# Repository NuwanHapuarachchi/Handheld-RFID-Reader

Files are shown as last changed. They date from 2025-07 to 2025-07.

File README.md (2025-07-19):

# Handheld RFID Reader

This repository contains the complete design files, firmware, software, and documentation for a **Handheld High-Frequency (HF) RFID Reader**. This project was developed as a partial fulfillment of the requirements for the module **EN 2161: Electronic Design Realization** at the Department of Electronic & Telecommunication Engineering, University of Moratuwa.

### 📋 Table of Contents

- [Features](#-features)
- [System Architecture](#️-system-architecture)
- [Hardware Design](#️-hardware-design)
- [Antenna Parameters](#-antenna-parameters)
- [PCB Design](#-pcb-design)
- [Enclosure Design](#-enclosure-design)
- [Software & Firmware](#-software--firmware)
- [Gallery](#-gallery)
- [Installation](#-installation)
- [Usage](#-usage)
- [Project Team](#-project-team)
- [Acknowledgments](#-acknowledgments)

### ✨ Features

- **Ergonomic Design**: A comfortable, gun-shaped enclosure with an ergonomic handle, designed in SolidWorks and 3D printed for industry-level durability
- **HF RFID Capability**: Reads HF (13.56 MHz) RFID tags, supporting the ISO 15693 standard
- **Wireless Connectivity**: Integrated ESP8266 Wi-Fi module for direct communication with a cloud database, offering greater range and flexibility compared to Bluetooth
- **Modular PCB Design**: Three separate 2-layer PCBs for the Antenna, MCU, and Power circuits to ensure signal integrity and simplify debugging
- **Rechargeable Power System**: Powered by two 18650 Li-Ion batteries (total capacity ~3600 mAh), with a dedicated charging cradle and a Battery Management System (BMS) for safety and longevity
- **User Interface**: 
  - LED indicators for power, Wi-Fi status, and read confirmation
  - A comprehensive Web Application (Node.js) for system management, data visualization, and device configuration
  - A cross-platform Mobile Application (Flutter) for on-the-go data access and monitoring
- **Centralized Database**: Utilizes Supabase (PostgreSQL) for robust, scalable, and secure data storage with row-level security policies

### 🛠️ Hardware Design

### Key Components

| Component | Selected Model | Reason for Selection |
|---|---|---|
| **RFID Frontend** | NXP PN5180 | High performance, excellent documentation, and support for ISO 15693 |
| **Microcontroller** | Atmel ATmega32U4 | Native USB support, sufficient I/O, and strong community support |
| **Wi-Fi Module** | Espressif ESP8266 | Direct internet access, high data throughput, and large developer community |
| **Battery** | 2x Li-Ion 18650 (3600 mAh) | High capacity for full-shift operation, good availability, and safety |

### 📡 Antenna Parameters

A custom 2-turn PCB trace antenna was designed for the 13.56 MHz frequency. The design was simulated and optimized for performance.

| Parameter | Value | Unit | Description |
|---|---|---|---|
| **Operating Frequency** | 13.56 | MHz | HF RFID frequency |
| **Target Impedance** | 20 | Ω | Antenna impedance |
| **Antenna Dimensions** | 65 x 65 | mm | Physical size |
| **Number of Turns (N)** | 2 | - | Antenna coil turns |
| **Track Width (w)** | 500 | µm | PCB trace width |
| **Gap between tracks (g)** | 500 | µm | Spacing between traces |
| **Simulated Inductance** | 891 | nH | Calculated inductance |
| **Simulated Capacitance** | 2.3 | pF | Calculated capacitance |
| **Simulated Resistance** | 1.180 | Ω | Calculated resistance |

### 🔧 PCB Design

The system uses a modular approach with three separate 2-layer PCBs: **Antenna**, **MCU**, and **Power**. This separation minimizes interference and simplifies manufacturing.

### PCB Modules

| PCB Module | Function | Features |
|---|---|---|
| **Antenna PCB** | RF signal processing | Custom antenna design, impedance matching |
| **MCU PCB** | Main processing unit | ATmega32U4, PN5180 interface, ESP8266 communication |
| **Power PCB** | Power management | BMS, charging circuit, voltage regulation |

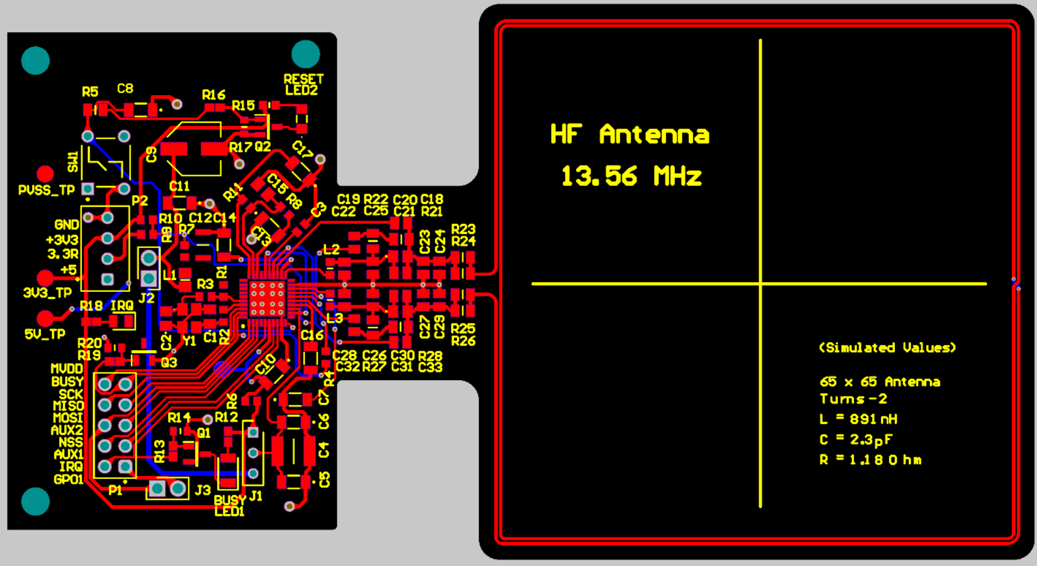
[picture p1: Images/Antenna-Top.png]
Antenna PCB
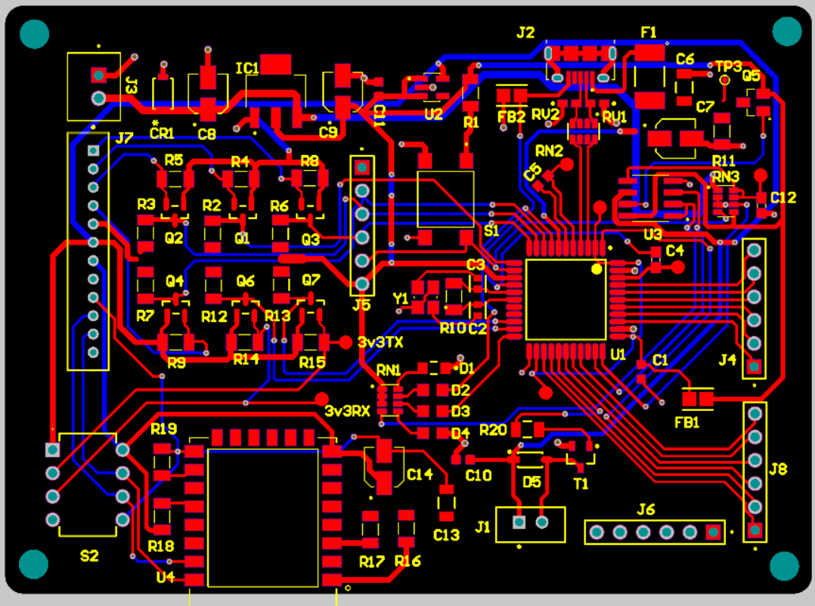
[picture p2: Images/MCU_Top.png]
MCU PCB
 

## 🏠 Enclosure Design

The enclosure and charging cradle were designed in **SolidWorks** for ergonomics, durability, and ease of assembly. The final models were 3D printed using ABS material.

### Design Features
- **Ergonomic gun-shaped design** for comfortable handheld operation
- **Robust ABS construction** for industrial durability
- **Integrated charging cradle** for convenient storage and charging
- **Professional finish** suitable for commercial applications

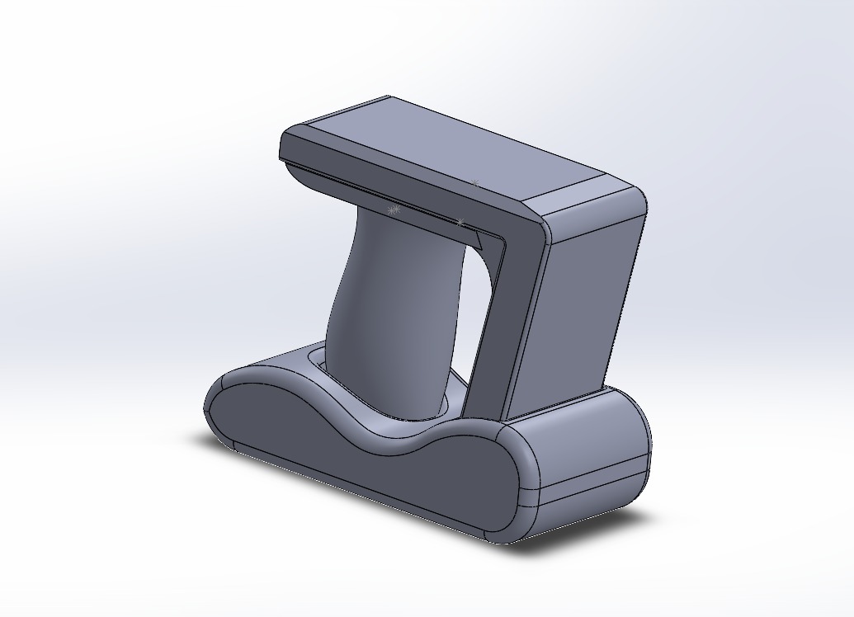
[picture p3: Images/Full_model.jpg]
Model
   

### Database Architecture

The backend uses **Supabase**, which provides a PostgreSQL database, authentication, and real-time APIs. The schema is designed to store information about users, readers, tags, and scan events.

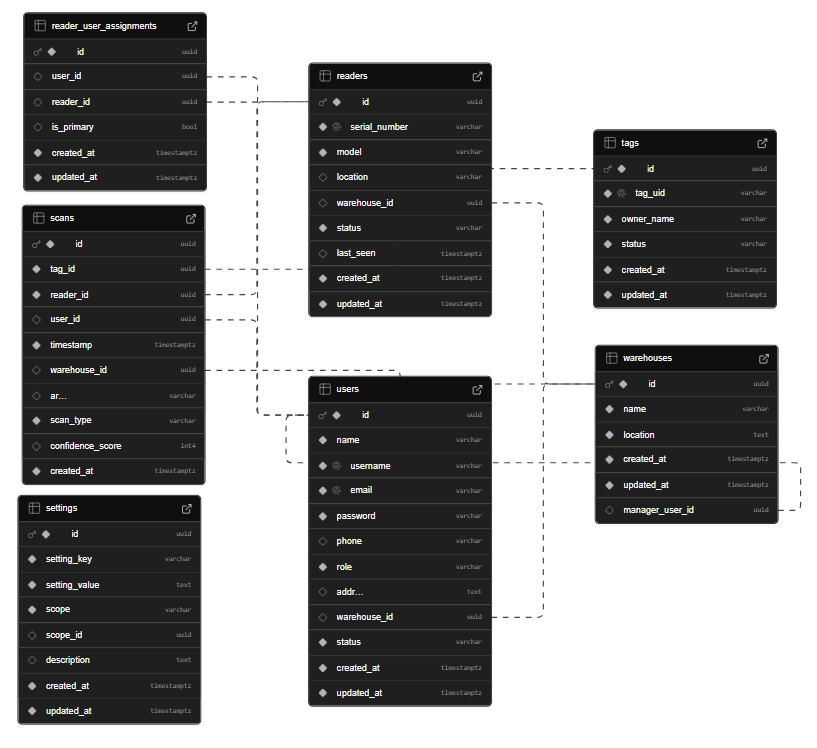
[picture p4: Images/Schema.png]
Database Schema


### Applications

#### Web Application
- **Technology**: Node.js
- **Features**: System management, data visualization, device configuration
- **Interface**: Responsive dashboard for administrators

#### Mobile Application  
- **Technology**: Flutter (Cross-platform)
- **Features**: On-the-go data access, real-time monitoring
- **Platforms**: iOS and Android support

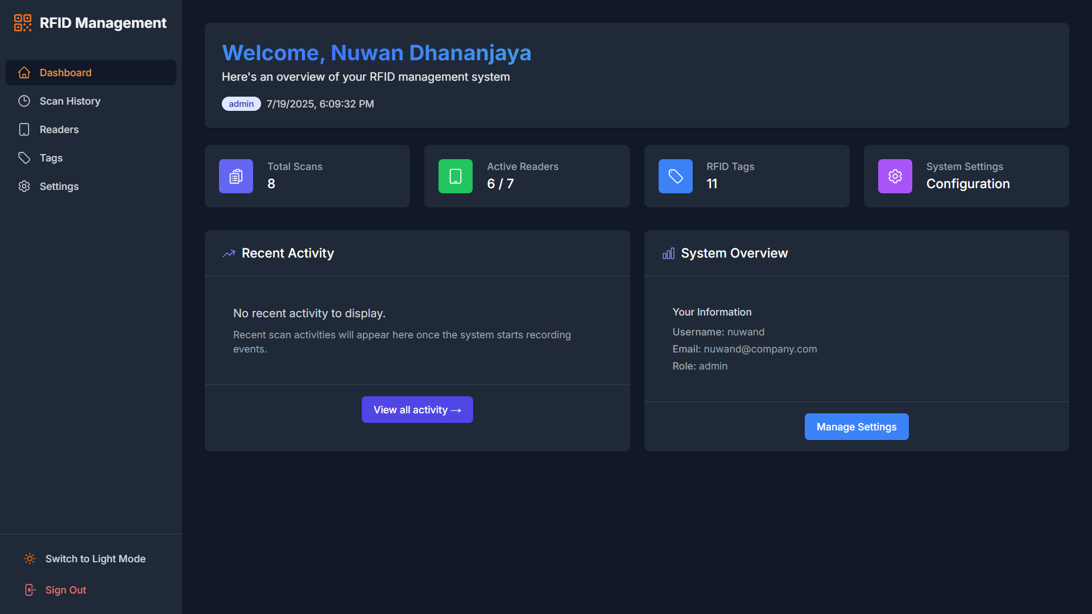
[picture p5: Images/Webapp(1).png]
Web Dashboard
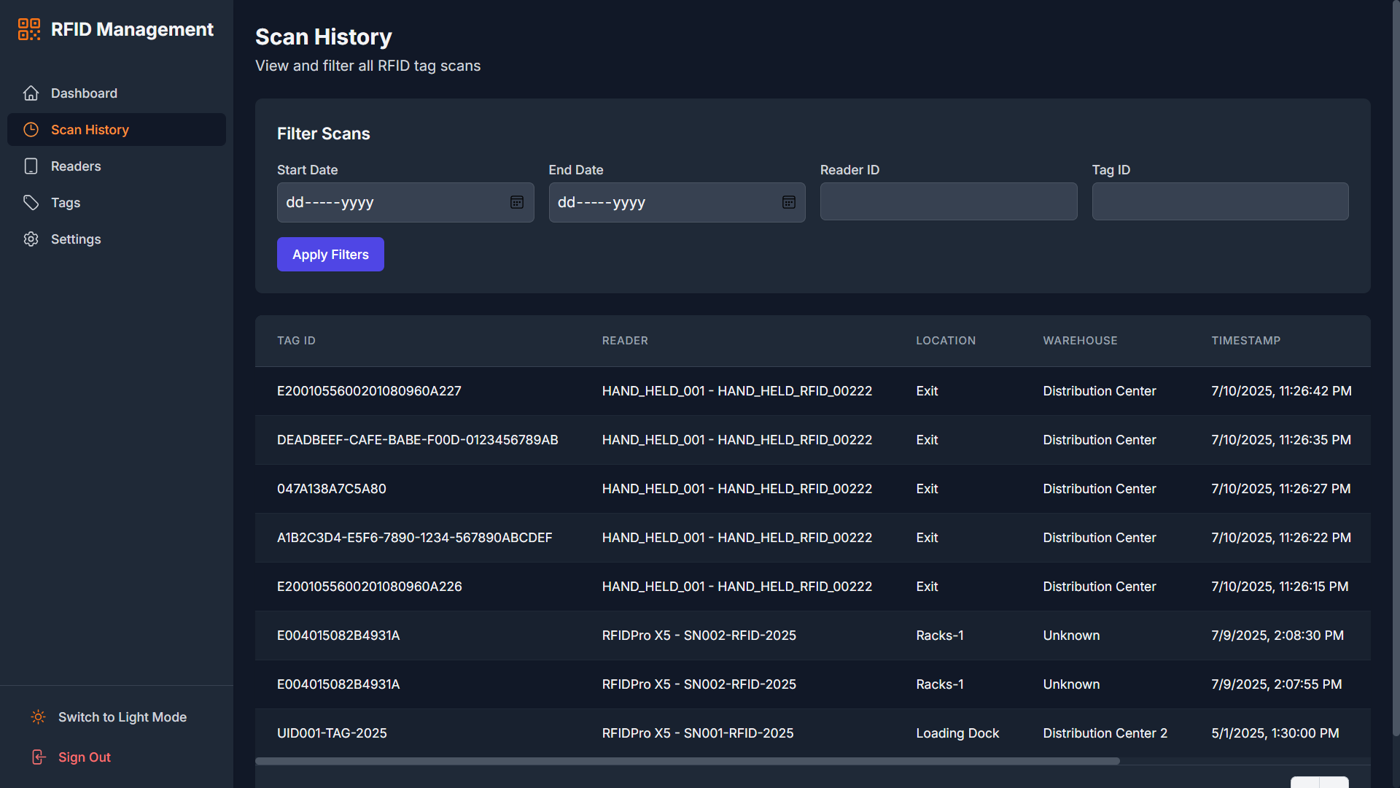
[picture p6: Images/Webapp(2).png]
Mobile Dashboard
 

## 📸 Gallery

### Final Product
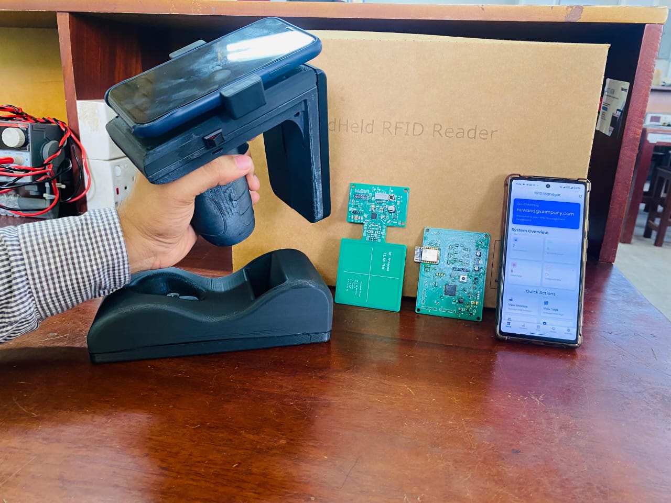
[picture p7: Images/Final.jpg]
3D Printed Final Product


## 🚀 Installation

### Hardware Setup
1. **Assembly**: Follow the assembly guide in `/docs/assembly_guide.pdf`
2. **PCB Installation**: Install the three PCB modules in the enclosure
3. **Battery Installation**: Insert two 18650 Li-Ion batteries
4. **Charging**: Place the device in the charging cradle

### Software Installation
1. **Firmware Upload**: 
   ```bash
   # Upload ATmega32U4 firmware
   avrdude -p atmega32u4 -c avr109 -U flash:w:rfid_reader.hex
   
   # Upload ESP8266 firmware
   esptool.py --port /dev/ttyUSB0 write_flash 0x00000 esp8266_firmware.bin
   ```

2. **Database Setup**:
   - Create a Supabase account
   - Import the database schema from `/database/schema.sql`
   - Configure environment variables

3. **Web Application**:
   ```bash
   cd web-app
   npm install
   npm start
   ```

4. **Mobile Application**:
   ```bash
   cd mobile-app
   flutter pub get
   flutter run
   ```

## 📱 Usage

### Basic Operation
1. **Power On**: Press and hold the power button
2. **Wi-Fi Connection**: Device automatically connects to configured network
3. **Tag Reading**: Point the antenna toward an RFID tag and press the trigger
4. **Data Sync**: Scan data is automatically synchronized to the cloud database
5. **Monitoring**: View real-time data through web or mobile applications

### Configuration
- Access the web dashboard to configure device settings
- Manage user permissions and access levels
- Monitor device status and battery levels
- Export scan data in various formats

## 👥 Project Team

This project was a collaborative effort by the following team members:

| Index No. | Name |
|---|---|
| 220235V | Ilukkumbura I.M.E.I.B. |
| 220212A | Hapuarachchi H.A.D.N.D. |
| 220162T | Fernando C.S.R. |
| 220221B | Hathurusingha H.A.R. |
| 220420J | Nawarathne M.A.A.K. |
| 220700T | Wickramasinghe S.D. |
| 220089B | Cooray M.S.T. |
| 220163X | Fernando D.S. |

## 📄 Documentation

### Available Reports
- **[Design Report](docs/EDR_Design_Report.pdf)**: Complete hardware design documentation
- **[Software Report](docs/Software_Report.pdf)**: Software architecture and implementation details
- **[Assembly Guide](docs/assembly_guide.pdf)**: Step-by-step assembly instructions
- **[User Manual](docs/user_manual.pdf)**: Operating instructions and troubleshooting

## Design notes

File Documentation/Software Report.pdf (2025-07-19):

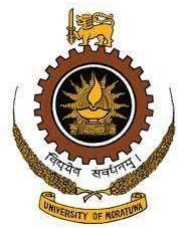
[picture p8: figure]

Department of Electronic & Telecommunication Engineering, University of Moratuwa,
Sri Lanka.

## Software Report Handheld RFID Reader

## Group Members

Index No | Name
220235V | Ilukkumbura I.M.E.I.B.
220212A | Hapuarachchi H.A.D.N.D.
220162T | Fernando C.S.R.
220221B | Hathurusingha HA.R.
220420J | Nawarathne MA.A.K.
220700T | Wickramasinghe S.D.
220089B | Cooray M.S.T.
220163X | Fernando D.S.

## Submitted in partial fulfillment of the requirements for the module EN 2161 Electronic Design Realization

5/22/2025

## Contents

1 PCB Design | 2
2 Enclosure Design | 2
3 Web App Development | 2
4 Database Implementation | 2
5 Schema | 2
6 Firmware Development | 8

1

## 1 PCB Design

## Altium Designer - https://www.altium.com/education/students

## 2 Enclosure Design

## SolidWorks

## 3 Web App Development

The web app was developed using Node.js.

## Link: https://uniofmoramy.sharepoint.com/:f:/g/personal/wickramasinghesd22uomlk/Emx1S− QY ZOlAi52qV PW JZnoBJQriCgSUmRu − N7Q6K0C1tQ?e = sf9qnY

## 4 Database Implementation

The database was implemented using Supabase(PostgreSQL).

## 5 Schema

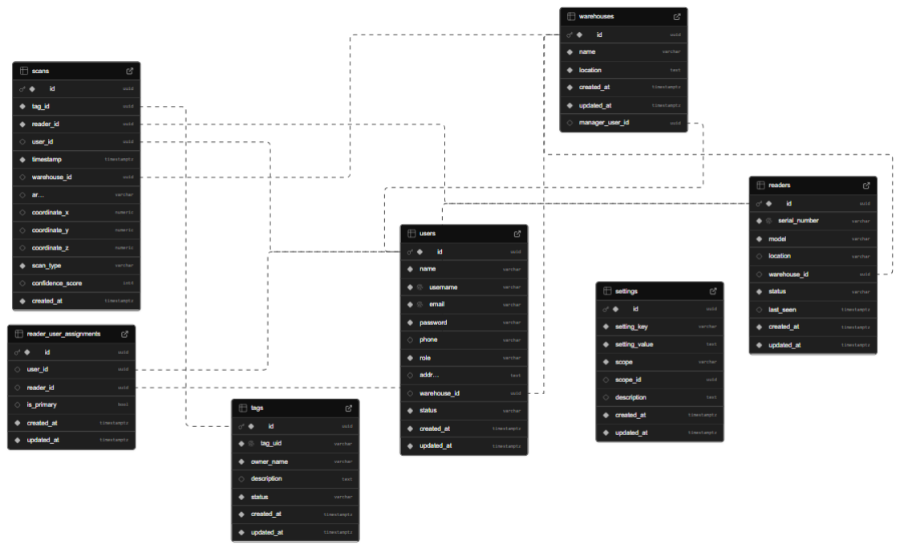
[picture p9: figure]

### Figure 1: Schema

1 | -- Drop tables if they exist for clean migration
2 | DROP TABLE IF EXISTS settings CASCADE ;
3 | DROP TABLE IF EXISTS scans CASCADE ;

2

DROP TABLE IF EXISTS tags CASCADE ;
DROP TABLE IF EXISTS reader_user_assignments CASCADE ; DROP TABLE IF EXISTS readers CASCADE ;
DROP TABLE IF EXISTS users CASCADE ;
DROP TABLE IF EXISTS warehouses CASCADE ;

-- Create warehouses table ( removed the manager_user_id initially to ,→ avoid circular reference )
CREATE TABLE warehouses (
id UUID PRIMARY KEY DEFAULT gen_random_uuid () ,
name VARCHAR (255) NOT NULL ,
location TEXT NOT NULL ,
created_at TIMESTAMPTZ NOT NULL DEFAULT NOW () , updated_at TIMESTAMPTZ NOT NULL DEFAULT NOW ()

) ;

-- Create users table
CREATE TABLE users (
id UUID PRIMARY KEY DEFAULT gen_random_uuid () , name VARCHAR (255) NOT NULL ,
username VARCHAR (100) NOT NULL UNIQUE ,
email VARCHAR (255) NOT NULL UNIQUE ,
password VARCHAR (255) NOT NULL ,
phone VARCHAR (20) ,
role VARCHAR (20) NOT NULL CHECK ( role IN (’admin ’, ’manager ’, ’ ,→ employee ’) ) ,
address TEXT ,
warehouse_id UUID REFERENCES warehouses (id) ON DELETE SET NULL , status VARCHAR (20) NOT NULL DEFAULT ’active ’ CHECK ( status IN (’ ,→ active ’, ’suspended ’, ’inactive ’) ) ,
created_at TIMESTAMPTZ NOT NULL DEFAULT NOW () ,
updated_at TIMESTAMPTZ NOT NULL DEFAULT NOW ()

) ;

-- Now add the manager_user_id to warehouses after users table exists ALTER TABLE warehouses ADD COLUMN manager_user_id UUID ;
ALTER TABLE warehouses ADD CONSTRAINT fk_warehouses_manager
FOREIGN KEY ( manager_user_id ) REFERENCES users (id) ON DELETE SET ,→ NULL ;

-- Create readers table
CREATE TABLE readers (
id UUID PRIMARY KEY DEFAULT gen_random_uuid () , serial_number VARCHAR (100) NOT NULL UNIQUE ,
model VARCHAR (100) NOT NULL ,
location VARCHAR (255) NOT NULL ,
warehouse_id UUID REFERENCES warehouses (id) ON DELETE SET NULL , status VARCHAR (20) NOT NULL DEFAULT ’active ’ CHECK ( status IN (’ ,→ active ’, ’maintenance ’, ’retired ’) ) ,
last_seen TIMESTAMPTZ ,
created_at TIMESTAMPTZ NOT NULL DEFAULT NOW () ,
updated_at TIMESTAMPTZ NOT NULL DEFAULT NOW ()

) ;

-- Create reader_user_assignments table for many - to - many relationship -- This is better than having assigned_user_id in readers table when ,→ multiple users can be assigned
CREATE TABLE reader_user_assignments (
id UUID PRIMARY KEY DEFAULT gen_random_uuid () ,

3

user_id UUID REFERENCES users (id) ON DELETE CASCADE , reader_id UUID REFERENCES readers (id) ON DELETE CASCADE , is_primary BOOLEAN DEFAULT false ,
created_at TIMESTAMPTZ NOT NULL DEFAULT NOW () , updated_at TIMESTAMPTZ NOT NULL DEFAULT NOW () ,
UNIQUE ( reader_id , user_id )

) ;

-- Create tags table
CREATE TABLE tags (
id UUID PRIMARY KEY DEFAULT gen_random_uuid () , tag_uid VARCHAR (100) NOT NULL UNIQUE ,
owner_name VARCHAR (255) NOT NULL ,
description TEXT ,
status VARCHAR (20) NOT NULL DEFAULT ’active ’ CHECK ( status IN (’ ,→ active ’, ’damaged ’, ’retired ’) ) ,
created_at TIMESTAMPTZ NOT NULL DEFAULT NOW () ,
updated_at TIMESTAMPTZ NOT NULL DEFAULT NOW ()

) ;

-- Create scans table
CREATE TABLE scans (
id UUID PRIMARY KEY DEFAULT gen_random_uuid () ,
tag_id UUID NOT NULL REFERENCES tags (id) ON DELETE CASCADE , reader_id UUID NOT NULL REFERENCES readers (id) ON DELETE CASCADE , user_id UUID REFERENCES users (id) ON DELETE SET NULL ,
timestamp TIMESTAMPTZ NOT NULL DEFAULT NOW () ,
warehouse_id UUID REFERENCES warehouses (id) ON DELETE SET NULL , area VARCHAR (255) ,
coordinate_x DECIMAL (10 , 2) ,
coordinate_y DECIMAL (10 , 2) ,
coordinate_z DECIMAL (10 , 2) ,
scan_type VARCHAR (20) NOT NULL CHECK ( scan_type IN (’entry ’, ’exit ’, ,→ ’inventory ’) ) ,
confidence_score INTEGER CHECK ( confidence_score BETWEEN 0 AND 100) , created_at TIMESTAMPTZ NOT NULL DEFAULT NOW ()

) ;

-- Create settings table
CREATE TABLE settings (
id UUID PRIMARY KEY DEFAULT gen_random_uuid () ,
setting_key VARCHAR (100) NOT NULL ,
setting_value TEXT NOT NULL ,
scope VARCHAR (50) NOT NULL DEFAULT ’global ’ CHECK ( scope IN (’global ,→ ’, ’reader ’, ’warehouse ’) ) ,
scope_id UUID , -- This will store reader_id or warehouse_id based on ,→ scope
description TEXT ,
created_at TIMESTAMPTZ NOT NULL DEFAULT NOW () ,
updated_at TIMESTAMPTZ NOT NULL DEFAULT NOW ()

) ;

-- Add a partial unique constraint that treats NULL scope_id as a
,→ specific value
CREATE UNIQUE INDEX idx_settings_unique ON settings ( setting_key , scope , ,→ COALESCE ( scope_id , ’00000000 -0000 -0000 -0000 -000000000000 ’:: UUID ) ) ,→ ;

-- Create functions and triggers for updated_at timestamps

4

109 | CREATE OR REPLACE FUNCTION update_timestamp ()
110 | RETURNS TRIGGER AS $$
111 | BEGIN
112 | NEW . updated_at = NOW () ;
113 | RETURN NEW ;
114 | END ;
115 | $$ language ’plpgsql ’;

116
117 | -- Create triggers for each table
118 | CREATE TRIGGER update_warehouses_timestamp BEFORE UPDATE ON warehouses
119 | FOR EACH ROW EXECUTE PROCEDURE update_timestamp () ;
120 | CREATE TRIGGER update_users_timestamp BEFORE UPDATE ON users
121 | FOR EACH ROW EXECUTE PROCEDURE update_timestamp () ;
122 | CREATE TRIGGER update_readers_timestamp BEFORE UPDATE ON readers
123 | FOR EACH ROW EXECUTE PROCEDURE update_timestamp () ;
124 | CREATE TRIGGER update_tags_timestamp BEFORE UPDATE ON tags
125 | FOR EACH ROW EXECUTE PROCEDURE update_timestamp () ;
126 | CREATE TRIGGER update_settings_timestamp BEFORE UPDATE ON settings
127 | FOR EACH ROW EXECUTE PROCEDURE update_timestamp () ;
128 | CREATE TRIGGER update_reader_user_assignments_timestamp BEFORE UPDATE ON
,→ | reader_user_assignments
129 | FOR EACH ROW EXECUTE PROCEDURE update_timestamp () ;

130
131 | -- Create indexes for performance
132 | CREATE INDEX idx_scans_timestamp ON scans ( timestamp ) ;
133 | CREATE INDEX idx_scans_tag_id ON scans ( tag_id ) ;
134 | CREATE INDEX idx_scans_reader_id ON scans ( reader_id ) ;
135 | CREATE INDEX idx_readers_warehouse ON readers ( warehouse_id ) ;
136 | CREATE INDEX idx_users_warehouse ON users ( warehouse_id ) ;
137 | CREATE INDEX idx_tags_status ON tags ( status ) ;
138 | -- We already have the unique index that acts as our index for these
,→ columns
139 | CREATE INDEX idx_reader_assignments_user ON reader_user_assignments (
,→ user_id ) ;
140 | CREATE INDEX idx_reader_assignments_reader ON reader_user_assignments (
,→ reader_id ) ;

141
142 | -- Create RLS ( Row Level Security ) policies for Supabase
143 | -- Enable RLS on all tables
144 | ALTER TABLE warehouses ENABLE ROW LEVEL SECURITY ;
145 | ALTER TABLE users ENABLE ROW LEVEL SECURITY ;
146 | ALTER TABLE readers ENABLE ROW LEVEL SECURITY ;
147 | ALTER TABLE tags ENABLE ROW LEVEL SECURITY ;
148 | ALTER TABLE scans ENABLE ROW LEVEL SECURITY ;
149 | ALTER TABLE settings ENABLE ROW LEVEL SECURITY ;
150 | ALTER TABLE reader_user_assignments ENABLE ROW LEVEL SECURITY ;

151
152 | -- Comprehensive RLS policies

153
154 | -- Warehouse policies
155 | CREATE POLICY " Admins can do anything with warehouses " ON warehouses
156 | FOR ALL TO authenticated
157 | USING ( auth . uid () IN ( SELECT id FROM users WHERE role = ’admin ’) ) ;

158
159 | CREATE POLICY " Managers can update their warehouses " ON warehouses
160 | FOR UPDATE TO authenticated
161 | USING ( auth . uid () = manager_user_id ) ;

162
163 | CREATE POLICY " All users can view warehouses " ON warehouses

5

164 | FOR SELECT TO authenticated
165 | USING ( true ) ;

166
167 | -- User policies
168 | CREATE POLICY " Admins can do anything with users " ON users
169 | FOR ALL TO authenticated
170 | USING ( auth . uid () IN ( SELECT id FROM users WHERE role = ’admin ’) ) ;

171
172 | CREATE POLICY " Managers can view and update users in their warehouse " ON
,→ | users
173 | FOR SELECT TO authenticated
174 | USING (
175 | ( auth . uid () IN ( SELECT id FROM users WHERE role = ’manager ’) )
176 | AND
177 | ( warehouse_id IN ( SELECT warehouse_id FROM users WHERE id = auth
,→ . uid () )
178 | OR warehouse_id IN ( SELECT id FROM warehouses WHERE
,→ manager_user_id = auth . uid () ) )
179 | ) ;

180
181 | CREATE POLICY " Users can view their own data " ON users
182 | FOR SELECT TO authenticated
183 | USING (id = auth . uid () ) ;

184
185 | -- Reader policies
186 | CREATE POLICY " Admins can do anything with readers " ON readers
187 | FOR ALL TO authenticated
188 | USING ( auth . uid () IN ( SELECT id FROM users WHERE role = ’admin ’) ) ;

189
190 | CREATE POLICY " Managers can manage readers in their warehouse " ON
,→ readers
191 | FOR ALL TO authenticated
192 | USING (
193 | ( auth . uid () IN ( SELECT id FROM users WHERE role = ’manager ’) )
194 | AND
195 | ( warehouse_id IN ( SELECT id FROM warehouses WHERE
,→ manager_user_id = auth . uid () ) )
196 | ) ;

197
198 | CREATE POLICY " Users can view readers they are assigned to" ON readers
199 | FOR SELECT TO authenticated
200 | USING (
201 | id IN (
202 | SELECT reader_id FROM reader_user_assignments
203 | WHERE user_id = auth . uid ()
204 | )
205 | ) ;

206
207 | -- Reader Assignment policies
208 | CREATE POLICY " Admins can do anything with reader assignments " ON
,→ reader_user_assignments
209 | FOR ALL TO authenticated
210 | USING ( auth . uid () IN ( SELECT id FROM users WHERE role = ’admin ’) ) ;

211
212 | CREATE POLICY " Managers can manage reader assignments in their warehouse
,→ " ON reader_user_assignments
213 | FOR ALL TO authenticated
214 | USING (
215 | ( auth . uid () IN ( SELECT id FROM users WHERE role = ’manager ’) )

6

216 | AND
217 | ( reader_id IN (
218 | SELECT id FROM readers
219 | WHERE warehouse_id IN (
220 | SELECT id FROM warehouses
221 | WHERE manager_user_id = auth . uid ()
222 | )
223 | ) )
224 | ) ;

225
226 | CREATE POLICY " Users can view their reader assignments " ON
| ,→ reader_user_assignments
227 | FOR SELECT TO authenticated
228 | USING ( user_id = auth . uid () ) ;

229
230 | -- Tags policies
231 | CREATE POLICY " Admins can do anything with tags " ON tags
232 | FOR ALL TO authenticated
233 | USING ( auth . uid () IN ( SELECT id FROM users WHERE role = ’admin ’) ) ;

234
235 | CREATE POLICY " All authenticated users can view tags " ON tags
236 | FOR SELECT TO authenticated
237 | USING ( true ) ;

238
239 | -- Scans policies
240 | CREATE POLICY " Admins can do anything with scans " ON scans
241 | FOR ALL TO authenticated
242 | USING ( auth . uid () IN ( SELECT id FROM users WHERE role = ’admin ’) ) ;

243
244 | CREATE POLICY " Managers can view scans in their warehouse " ON scans
245 | FOR SELECT TO authenticated
246 | USING (
247 | ( auth . uid () IN ( SELECT id FROM users WHERE role = ’manager ’) )
248 | AND
249 | ( warehouse_id IN ( SELECT id FROM warehouses WHERE
| ,→ manager_user_id = auth . uid () ) )
250 | ) ;

251
252 | CREATE POLICY " Users can view their scans " ON scans
253 | FOR SELECT TO authenticated
254 | USING ( user_id = auth . uid () ) ;

255
256 | -- Settings policies
257 | CREATE POLICY " Admins can do anything with settings " ON settings
258 | FOR ALL TO authenticated
259 | USING ( auth . uid () IN ( SELECT id FROM users WHERE role = ’admin ’) ) ;

260
261 | CREATE POLICY " All authenticated users can view global settings " ON
| ,→ settings
262 | FOR SELECT TO authenticated
263 | USING ( scope = ’global ’) ;

264
265 | CREATE POLICY " Managers can view and edit settings for their warehouse "
| ,→ ON settings
266 | FOR ALL TO authenticated
267 | USING (
268 | ( auth . uid () IN ( SELECT id FROM users WHERE role = ’manager ’) )
269 | AND
270 | (

7

271 | ( scope = ’warehouse ’ AND scope_id IN (
272 | SELECT id FROM warehouses WHERE manager_user_id = auth . ,→ uid ()
273 | ) )
274 | OR
275 | ( scope = ’reader ’ AND scope_id IN (
276 | SELECT id FROM readers
277 | WHERE warehouse_id IN (
278 | SELECT id FROM warehouses WHERE manager_user_id = ,→ auth . uid ()
279 | )
280 | ) )
281 | )
282 | ) ;

## 6 Firmware Development

## 6.1 Atmgea32u4 Programming Code (.cpp)

1 | # include <avr/io.h>
2 | # include <util / delay .h>
3 | # include <stdio .h>
4 | # include <string .h>
5 | # include <stdint .h>
6 | # include " mySPI .h"
7 | # include " PN5180 .h"
8 | # include " myUART .h"

9
10 | // Define F_CPU if not already defined
11 | # ifndef F_CPU
12 | # define F_CPU 16000000 UL
13 | # endif

14
15 | // Buffer size for UID string
16 | # define UID_STRING_SIZE 32

17
18 | // PN5180 instance ( NSS = PD1 / Pin 2 , BUSY = PB6 / Pin 10 , RST = PB4 / Pin 8)
19 | PN5180 pn5180 (/* NSS / 2 , / BUSY / 10 , / RST */ 8) ;

20
21 | // Function prototypes
22 | int handshake ( void ) ;
23 | int connectWiFi ( void ) ;
24 | void uart_transmit ( const char * data ) ; // For debug output
25 | void uart_transmit_num ( int16_t num ) ; | // For number output

26
27 | int main ( void ) {
28 | // Initialize UART ( USART1 )
29 | USART_Init () ;

30
31 | // Initialize SPI
32 | SPI_init () ;
33 | SPI_setConfig () ;

34
35 | // Initialize PN5180
36 | pn5180 . begin () ;

37

8

38 | // Configure Pin 12 ( PD6 ) as input with pull - up , Pin 6 ( PD7 ) as
,→ output
39 | DDRD &= ~(1 << DDD6 ) ; | // PD6 as input ( button )
40 | DDRD |= (1 << DDD7 ) ; | // PD7 as output ( LED )
41 | PORTD |= (1 << PORTD6 ) ; // Enable pull - up on PD6
42 | PORTD &= ~(1 << PORTD7 ) ; // LED off initially

43
44 | // Handshake with ESP
45 | for ( uint8_t retries = 3; retries > 0; retries - -) {
46 | USART_TransmitCommand (" PING ") ;
47 | int response = handshake () ;
48 | if ( response == 3) break ; // OK received
49 | _delay_ms (500) ;
50 | }

51
52 | // Connect to WiFi
53 | int wifiStatus = connectWiFi () ;
54 | char wifiMsg [32];
55 | snprintf ( wifiMsg , sizeof ( wifiMsg ) , " WiFi Status : %d\r\n", wifiStatus
| ,→ ) ;
56 | uart_transmit ( wifiMsg ) ;

57
58 | // Main loop
59 | while (1) {
60 | if (!( PIND & (1 << PIND6 ) ) ) { // Button pressed ( PD6 low )
61 | _delay_ms (50) ; // Debounce
62 | if (!( PIND & (1 << PIND6 ) ) ) { // Confirm button
,→ press
63 | | uint8_t uid [8];
64 | | if ( pn5180 . getInventoryFake ( uid ) ) {
65 | | char uidStr [17];
66 | | for (int i = 7 , j = 0; i >= 0; i - - ,
| | ,→ j += 2) {
67 | | sprintf ( uidStr + j , "%02 X",
| | ,→ uid [ i ]) ;
68 | | }
69 | | char cmd [32];
70 | | snprintf ( cmd , sizeof ( cmd ) , " SEND :UID
| | ,→ :%s", uidStr ) ;
71 | | USART_TransmitCommand ( cmd ) ; // Send
| | ,→ UID to NodeMCU
72 | | int response = USART_ReceiveCommand
| | ,→ () ;
73 | | char responseMsg [16];
74 | | snprintf ( responseMsg , sizeof (
| | ,→ responseMsg ) , " Response : %d\r\
| | ,→ n", response ) ;
75 | | uart_transmit ( responseMsg ) ;
76 | | if ( response == 3) {
77 | | PORTD |= (1 << PORTD7 ) ; //
| | ,→ LED on
78 | | _delay_ms (500) ;
79 | | PORTD &= ~(1 << PORTD7 ) ; //
| | ,→ LED off
80 | | } else if ( response == 2) {
81 | | // Handle ERROR ( add if
| | ,→ needed )
82 | | }
83 | | }

9

while (!( PIND & (1 << PIND6 ) ) ) { _delay_ms (10) ; // Wait for button ,→ release

}

}

}

}

return 0; // Never reached

}

// UART transmit function for strings void uart_transmit ( const char * data ) { while (* data ) {
while (!( UCSR1A & (1 << UDRE1 ) ) ) ; // Wait for empty transmit ,→ buffer
UDR1 = * data ++; // Send character

}

}

// UART transmit function for numbers
void uart_transmit_num ( int16_t num ) {
char buffer [16];
snprintf (buffer , sizeof ( buffer ) , "%d\r\n", num ) ; uart_transmit ( buffer ) ;

}

// Handshake with ESP
int handshake ( void ) {
_delay_ms (500) ;
USART_TransmitCommand (" PING ") ;
uart_transmit (" Waiting for ESP response ...\ r\n") ;

// Wait for response with timeout (~3 seconds )
char response [ MAX_BUFFER_SIZE ] = {0};
for ( uint32_t i = 0; i < 3000000; i ++) { // Approx 3 seconds at 16 ,→ MHz
USART_ReadString ( response , MAX_BUFFER_SIZE , 1000) ; // Short ,→ timeout per read
if ( strlen ( response ) > 0) {
| char debugMsg [128]; snprintf ( debugMsg , sizeof ( debugMsg ) , " Received from ,→ ESP : %s\r\n", response ) ; uart_transmit ( debugMsg ) ; if ( strcmp ( response , "OK") == 0) {

uart_transmit ("ESP communication successful ,→ .\r\n") ;
return 3;
} else {
uart_transmit ("ESP responded incorrectly .\r\ ,→ n") ;
return -1;
| }

}
_delay_us (1) ; // Small delay

}

uart_transmit (" Timeout waiting for ESP .\r\n") ; return -1;

10

136 | }

137
138 | // Connect to WiFi
139 | int connectWiFi ( void ) {
140 | const uint32_t maxTimeout = 30000000; // ~30 seconds at 16 MHz
141 | const uint32_t retryInterval = 12000000; // ~12 seconds per attempt
142 | uint32_t attemptCount = maxTimeout / retryInterval ;

143
144 | for ( uint32_t attempt = 0; attempt < attemptCount ; attempt ++) {
145 | USART_TransmitCommand (" WIFI : CONNECT ") ;
146 | char response [ MAX_BUFFER_SIZE ] = {0};

147
148 | // Wait for response
149 | for ( uint32_t i = 0; i < retryInterval ; i ++) {
150 | USART_ReadString ( response , MAX_BUFFER_SIZE , 1000) ;
,→ // Short timeout
151 | if ( strlen ( response ) > 0) {
152 | if ( strcmp ( response , "OK") == 0) {
153 | return 3;
154 | } else if ( strcmp ( response , " ERROR ")
,→ | == 0) {
155 | break ;
156 | }
157 | }
158 | _delay_us (1) ; // Small delay
159 | }

160

161 | }
162 | return -1;
163 | }

## 6.2 PN5180 Programming Code (.h)

1 | /*
2 | * PN5180 . h
3 | *
4 | * Created : 5/22/2025 1:47:50 PM
5 | * | Author : AGRA
6 | */

7
8 | # ifndef PN5180_H
9 | # define PN5180_H

10
11 | # include " mySPI .h"

12
13 | // PN5180 Commands
14 | # define PN5180_WRITE_REGISTER | (0 x00)
15 | # define PN5180_WRITE_REGISTER_OR_MASK | (0 x01)
16 | # define PN5180_WRITE_REGISTER_AND_MASK | (0 x02)
17 | # define PN5180_READ_REGISTER | (0 x04)
18 | # define PN5180_WRITE_EEPROM | (0 x06)
19 | # define PN5180_READ_EEPROM | (0 x07)
20 | # define PN5180_SEND_DATA | (0 x09)
21 | # define PN5180_READ_DATA | (0 x0A)
22 | # define PN5180_LOAD_RF_CONFIG | (0 x11)
23 | # define PN5180_RF_ON | (0 x16)
24 | # define PN5180_RF_OFF | (0 x17)

11

25 | // 11.9.1 , Table 73 PN5180 Register Address Overview
26 | # define SYSTEM_CONFIG | (0 x00)
27 | # define IRQ_ENABLE | (0 x01)
28 | # define IRQ_STATUS | (0 x02)
29 | # define IRQ_CLEAR | (0 x03)
30 | # define RX_STATUS | (0 x13)
31 | # define TX_WAIT_CONFIG | (0 x17)
32 | # define TX_CONFIG | (0 x18)
33 | // 11.9.1 , Table 76 IRQ_STATUS Register
34 | # define RX_IRQ_STAT | (1 < <0) | // End of RF reception IRQ
35 | # define TX_IRQ_STAT | (1 < <1) | // End of RF transmission
| ,→ IRQ
36 | # define IDLE_IRQ_STAT | (1 < <2) | // Idle IRQ
37 | # define RFOFF_DET_IRQ_STAT | (1 < <6) | // RF Field OFF detection
| ,→ IRQ
38 | # define RFON_DET_IRQ_STAT | (1 < <7) | // RF Field ON detection IRQ
39 | # define TX_RFOFF_IRQ_STAT | (1 < <8) | // RF Field OFF in PCD IRQ
40 | # define TX_RFON_IRQ_STAT | (1 < <9) | // RF Field ON in PCD IRQ
41 | // 11.9.1 Table 92 RX_STATUS Register
42 | # define RX_COLL_POS (1 < <19) // These bits show the bit position of the
,→ first detected collision in a received frame (7 bits )
43 | # define RX_COLLISION_DETECTED (1 < <18) // This flag is set to 1 , when a
| ,→ collision has occurred
44 | // 11.9.1 Table 97 TX_CONFIG Register
45 | # define TX_DATA_ENABLE (1 < <10) // If set to 1 , transmission of data is
,→ enabled otherwise only symbols are transmitted .

46
47 | // The PN5180 receive buffer can hold a max of 508 bytes
48 | // But we only need to transfer 2 bytes + 8 bytes per tag = 10 bytes for
,→ | a single card
49 | # ifndef READ_BUFFER_SIZE
50 | # define READ_BUFFER_SIZE 10
51 | # endif
52 | // Other constants and enums
53 | enum ISO15693ErrorCode {
54 | EC_NO_CARD = -1 ,
55 | ISO15693_EC_OK = 0 ,
56 | ISO15693_EC_NOT_SUPPORTED = 0 x01 ,
57 | ISO15693_EC_NOT_RECOGNIZED = 0 x02 ,
58 | ISO15693_EC_OPTION_NOT_SUPPORTED = 0 x03 ,
59 | ISO15693_EC_UNKNOWN_ERROR = 0 x0F ,
60 | ISO15693_EC_BLOCK_NOT_AVAILABLE = 0 x10 ,
61 | ISO15693_EC_BLOCK_ALREADY_LOCKED = 0 x11 ,
62 | ISO15693_EC_BLOCK_IS_LOCKED = 0 x12 ,
63 | ISO15693_EC_BLOCK_NOT_PROGRAMMED = 0 x13 ,
64 | ISO15693_EC_BLOCK_NOT_LOCKED = 0 x14 ,
65 | ISO15693_EC_CUSTOM_CMD_ERROR = 0 xA0
66 | };

67
68 | class PN5180 {
69 | public :
70 | PN5180 ( uint8_t nssPin , uint8_t busyPin , uint8_t rstPin ) ;
71 | void begin () ;
72 | void hardReset () ;
73 | bool getInventory ( uint8_t * uid ) ;
74 | bool getInventoryFake ( uint8_t * uid ) ;
75 | void loadISO15693config () ;
76 | bool activateRF () ;
77 | bool disableRF () ;

12

78 | bool checkIdle () ;
79 | void clearIRQ () ;
80 | void setIdle () ;
81 | void activateTransceive () ;
82 | void sendInventoryCmd () ;
83 | void sendEndOfFrame () ;
84 | bool readReceptionBuffer ( uint8_t * buffer , int16_t len) ;
85 | uint32_t readRegister ( uint8_t regAddress ) ;
86 | bool sendBytes ( uint8_t * sendBuffer , size_t sendBufferLen ) ;
87 | bool readBytes ( uint8_t * recvBuffer , size_t recvBufferLen ) ;

88
89 | private :
90 | uint8_t _nss , _busy , _rst ;
91 | // SPISettings _spiSettings ;
92 | uint16_t _commandTimeout = 800;
93 | bool waitUntilAvailable () ;
94 | bool waitUntilBusy () ;
95 | void errorHandler ( ISO15693ErrorCode errorCode ) ;

96
97 | uint8_t * buffer = ( uint8_t *) malloc ( READ_BUFFER_SIZE ) ;
98 | };

99
100 | # endif

## 6.3 SPI Programming Code

6.3.1 .h

1 | # ifndef MYUART_H
2 | # define MYUART_H

3
4 | # include <stdint .h>

5
6 | # define RX_BUFFER_SIZE 64
7 | # define MAX_BUFFER_SIZE 100

8
9 | void USART_Init ( void ) ;
10 | void USART_Transmit ( uint8_t data ) ;
11 | uint8_t USART_Receive ( void ) ;
12 | void USART_TxString ( const char * str) ;
13 | void USART_ReadString ( char * buffer , uint8_t maxLen , uint32_t timeout ) ;
14 | int USART_ReceiveCommand ( void ) ;
15 | void USART_TransmitCommand ( const char * cmd ) ;

16
17 | # endif

### 6.3.2 .cpp

1 | /*
2 | * mySPI . cpp
3 | *
4 | * Created : 5/22/2025 1:46:21 PM
5 | * | Author : AGRA
6 | */

7
8 | # include <avr/io.h>

13

9 | # include <util / delay .h>
10 | # include <stdio .h>
11 | # include <stdint .h>
12 | # include " mySPI .h"

13
14 | // Define F_CPU if not already defined
15 | # ifndef F_CPU
16 | # define F_CPU 16000000 UL
17 | # endif

18

19
20 | // Initialize SPI as Master , Mode 0 ( CPOL =0 , CPHA =0) , 125 kHz ( F_CPU
| ,→ /128)
21 | void SPI_init ( void ) {
22 | // Set MOSI ( PB2 ) , SCK ( PB1 ) , and NSS ( PD1 ) as outputs ; MISO ( PB3 )
| ,→ as input
23 | DDRB |= (1 << DDB2 ) | (1 << DDB1 ) ; // MOSI , SCK
24 | DDRD |= (1 << DDD1 ) ; | // NSS
25 | DDRB &= ~(1 << DDB3 ) ; | // MISO as input

26
27 | // Configure SPI : Master , Mode 0 , 125 kHz
28 | SPCR = (1 << SPE ) | (1 << MSTR ) | (1 << SPR1 ) | (1 << SPR0 ) ;
29 | SPSR &= ~(1 << SPI2X ) ;
30 | }

31
32 | // Reapply SPI configuration ( for PN5180 compatibility )
33 | void SPI_setConfig ( void ) {
34 | // Reapply SPI settings : Master , Mode 0 , 125 kHz
35 | SPCR = (1 << SPE ) | (1 << MSTR ) | (1 << SPR1 ) | (1 << SPR0 ) ;
36 | SPSR &= ~(1 << SPI2X ) ;

37

38 | }

39
40 | // Perform bidirectional SPI transfer
41 | void SPI_transfer ( uint8_t * buffer , size_t length ) {
42 | for ( size_t i = 0; i < length ; i ++) {
43 | SPDR = buffer [ i ]; // Write byte to SPDR
44 | while (!( SPSR & (1 << SPIF ) ) ) ; // Wait for transmission complete
45 | buffer [ i ] = SPDR ; // Read received byte
46 | }
47 | }

48
49 | // Disable SPI
50 | void SPI_end ( void ) {
51 | SPCR &= ~(1 << SPE ) ; // Disable SPI
52 | }

53
54 | // Test SPI communication
55 | void SPI_testCommunication ( void ) {
56 | SPI_init () ;

57
58 | uint8_t data = 0 x55 ; // Arbitrary test byte
59 | uint8_t received ;

60
61 | // Pull NSS ( PD1 ) low to start communication
62 | PORTD &= ~(1 << PORTD1 ) ;
63 | _delay_ms (1) ;

64
65 | // Send and receive 1 byte

14

66 | SPDR = data ;
67 | while (!( SPSR & (1 << SPIF ) ) ) ;
68 | received = SPDR ;

69
70 | // Pull NSS high to end communication
71 | PORTD |= (1 << PORTD1 ) ;
72 | }

## 6.4 UART Programming Code

6.4.1 .h

1 | # ifndef MYUART_H
2 | # define MYUART_H

3
4 | # include <stdint .h>

5
6 | # define RX_BUFFER_SIZE 64
7 | # define MAX_BUFFER_SIZE 100

8
9 | void USART_Init ( void ) ;
10 | void USART_Transmit ( uint8_t data ) ;
11 | uint8_t USART_Receive ( void ) ;
12 | void USART_TxString ( const char * str) ;
13 | void USART_ReadString ( char * buffer , uint8_t maxLen , uint32_t timeout ) ;
14 | int USART_ReceiveCommand ( void ) ;
15 | void USART_TransmitCommand ( const char * cmd ) ;

16
17 | # endif

### 6.4.2 .cpp

1 | /*
2 | * myUART . cpp
3 | *
4 | * Created : 5/22/2025 1:44:47 PM
5 | * | Author : AGRA
6 | */

7
8 | # include <avr/io.h>
9 | # include <util / delay .h>
10 | # include <stdio .h>
11 | # include <string .h>
12 | # include <stdint .h>
13 | # include " myUART .h"

14
15 | // Define F_CPU if not already defined
16 | # ifndef F_CPU
17 | # define F_CPU 16000000 UL
18 | # endif

19
20 | // UART buffers
21 | volatile static uint8_t rx_buffer [ RX_BUFFER_SIZE ] = {0};
22 | volatile static uint16_t rx_count = 0;
23 | volatile static uint8_t uart_tx_busy = 1;
24 | static char rxBuffer [ MAX_BUFFER_SIZE ];

15

static uint8_t index = 0;

// UART transmit function ( for debug output , consistent with previous ,→ files )
static void uart_transmit ( const char * data ) {
while (* data ) {
while (!( UCSR1A & (1 << UDRE1 ) ) ) ; // Wait for empty transmit ,→ buffer
UDR1 = * data ++; // Send character

}

}

// Initialize USART1 : 9600 baud , 8 - bit , 1 stop bit , no parity , ,→ asynchronous
void USART_Init ( void ) {
// Set baud rate to 9600 (16 MHz -> UBRR1 = 103)
UBRR1 = 103;

// Enable transmitter and receiver
UCSR1B = (1 << RXEN1 ) | (1 << TXEN1 ) ;

// Set frame format : 8 - bit data , 1 stop bit , no parity , asynchronous
UCSR1C = (1 << UCSZ11 ) | (1 << UCSZ10 ) ;
UCSR1B &= ~(1 << UCSZ12 ) ; // Ensure 8 - bit data
UCSR1C &= ~((1 << UMSEL11 ) | (1 << UMSEL10 ) | (1 << UPM11 ) | (1 <<
,→ UPM10 ) | (1 << USBS1 ) ) ;

// Normal speed ( disable double speed )
UCSR1A &= ~(1 << U2X1 ) ;

// Debug output
char msg [] = " USART1 initialized \r\n"; uart_transmit ( msg ) ;

}

// Transmit one byte
void USART_Transmit ( uint8_t data ) {
while (!( UCSR1A & (1 << UDRE1 ) ) ) ; // Wait for empty transmit buffer UDR1 = data ;

}

// Receive one byte
uint8_t USART_Receive ( void ) {
while (!( UCSR1A & (1 << RXC1 ) ) ) ; // Wait for data return UDR1 ;

}

// Transmit a null - terminated string void USART_TxString ( const char * str) { while (* str) {
USART_Transmit (* str ++) ;

}

}

// Receive a string into buffer ( non - blocking , with timeout )
void USART_ReadString ( char * buffer , uint8_t maxLen , uint32_t timeout ) { uint8_t index = 0;
buffer [0] = ’\0 ’; // Initialize buffer

16

80 | // Timeout loop (~10 ms at 16 MHz , adjusted for cycles )
81 | while ( timeout > 0) {
82 | if ( UCSR1A & (1 << RXC1 ) ) {
83 | char c = USART_Receive () ;
84 | if ( c == ’\n’) {
85 | buffer [ index ] = ’\0 ’; // Null - terminate
86 | return ;
87 | } else if ( index < maxLen - 1) {
88 | buffer [ index ++] = c ;
89 | } else {
90 | buffer [0] = ’\0 ’; // Overflow , return empty
,→ string
91 | return ;
92 | }
93 | }
94 | _delay_us (1) ; // ~1 | s | delay per iteration
95 | timeout - -;
96 | }
97 | buffer [0] = ’\0 ’; // Timeout , return empty string
98 | }

99
100 | // Receive and parse command
101 | int USART_ReceiveCommand ( void ) {
102 | char response [ MAX_BUFFER_SIZE ];
103 | USART_ReadString ( response , MAX_BUFFER_SIZE , 10000) ; // ~10 ms
| ,→ timeout

104
105 | // Debug output
106 | char debugMsg [128];
107 | snprintf ( debugMsg , sizeof ( debugMsg ) , " Received : %s\r\n", response ) ;
108 | uart_transmit ( debugMsg ) ;

109
110 | if ( strlen ( response ) == 0) {
111 | return 0; // No complete message
112 | }

113
114 | // Compare response
115 | if ( strcmp ( response , "OK") == 0) {
116 | return 1; // Success
117 | } else if ( strcmp ( response , " ERROR ") == 0) {
118 | return 2; // Failure
119 | } else if ( strncmp ( response , "DA", 2) == 0) {
120 | return 3; // Data received
121 | } else {
122 | return -1; // Unknown response
123 | }
124 | }

125
126 | // Transmit command with " CMD:" prefix and ’\n’
127 | void USART_TransmitCommand ( const char * cmd ) {
128 | char buffer [ MAX_BUFFER_SIZE ] = {0};
129 | uint8_t len = strlen ( cmd ) ;

130
131 | // Add " CMD:" prefix and ’\n’ if needed
132 | if ( len > 0 && cmd [ len - 1] != ’\n’) {
133 | snprintf (buffer , MAX_BUFFER_SIZE - 1 , "CMD :%s\n", cmd ) ;
134 | } else {
135 | snprintf (buffer , MAX_BUFFER_SIZE - 1 , "CMD :%s", cmd ) ;
136 | }

17

137
138 | // Ensure null - termination
139 | buffer [ MAX_BUFFER_SIZE - 1] = ’\0 ’;

140
141 | // Send via UART
142 | USART_TxString ( buffer ) ;
143 | }

18

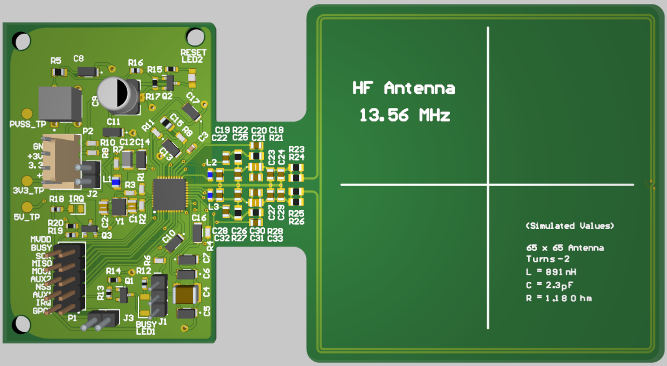
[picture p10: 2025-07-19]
Images/Antenna_3d.png

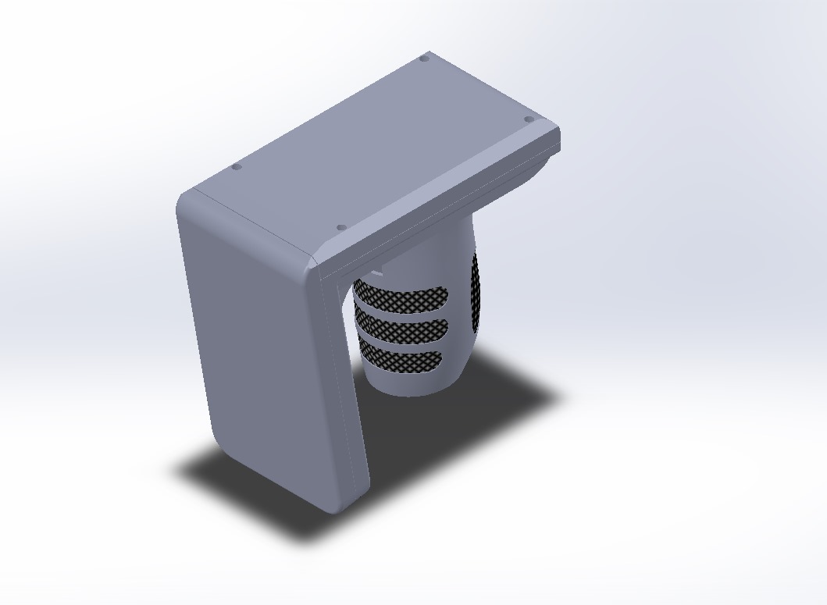
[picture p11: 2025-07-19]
Images/Enclosure.jpg

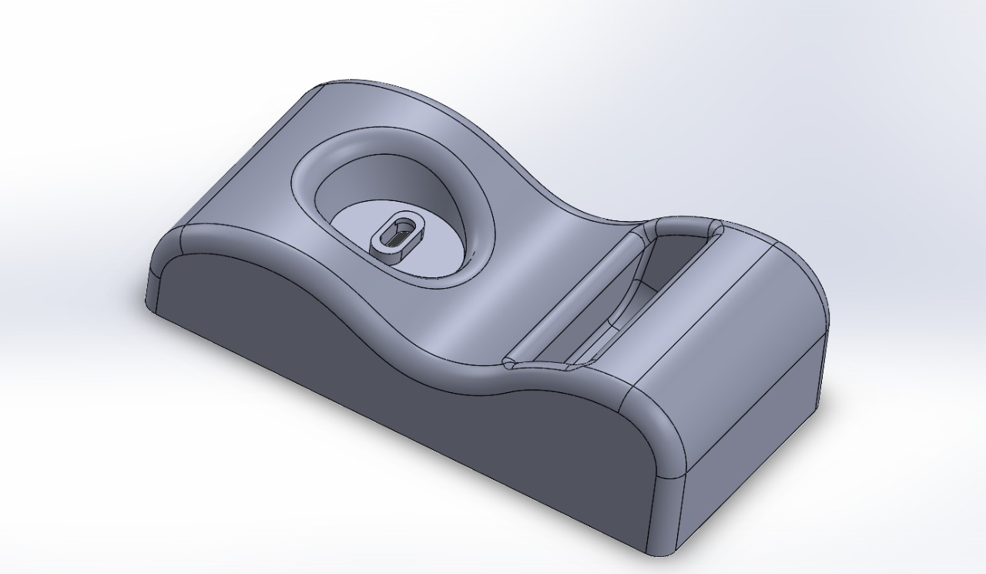
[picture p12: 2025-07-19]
Images/Cradle.jpg

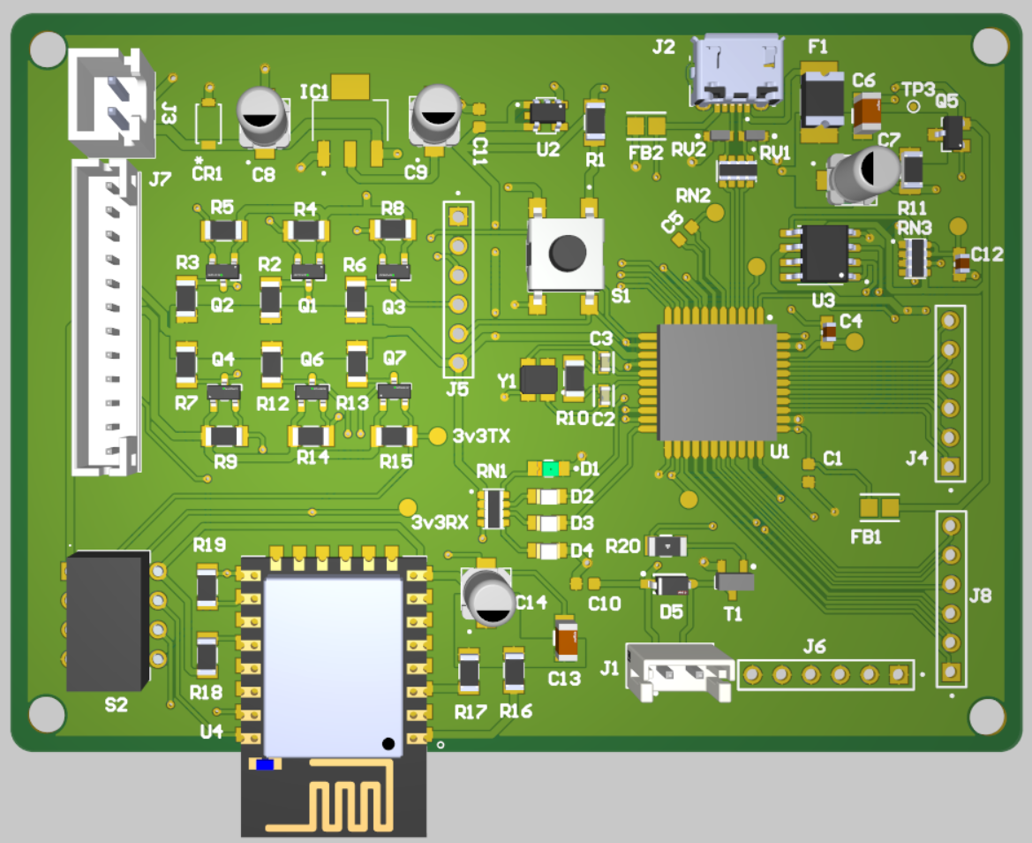
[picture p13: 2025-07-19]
Images/MCU_3d.png

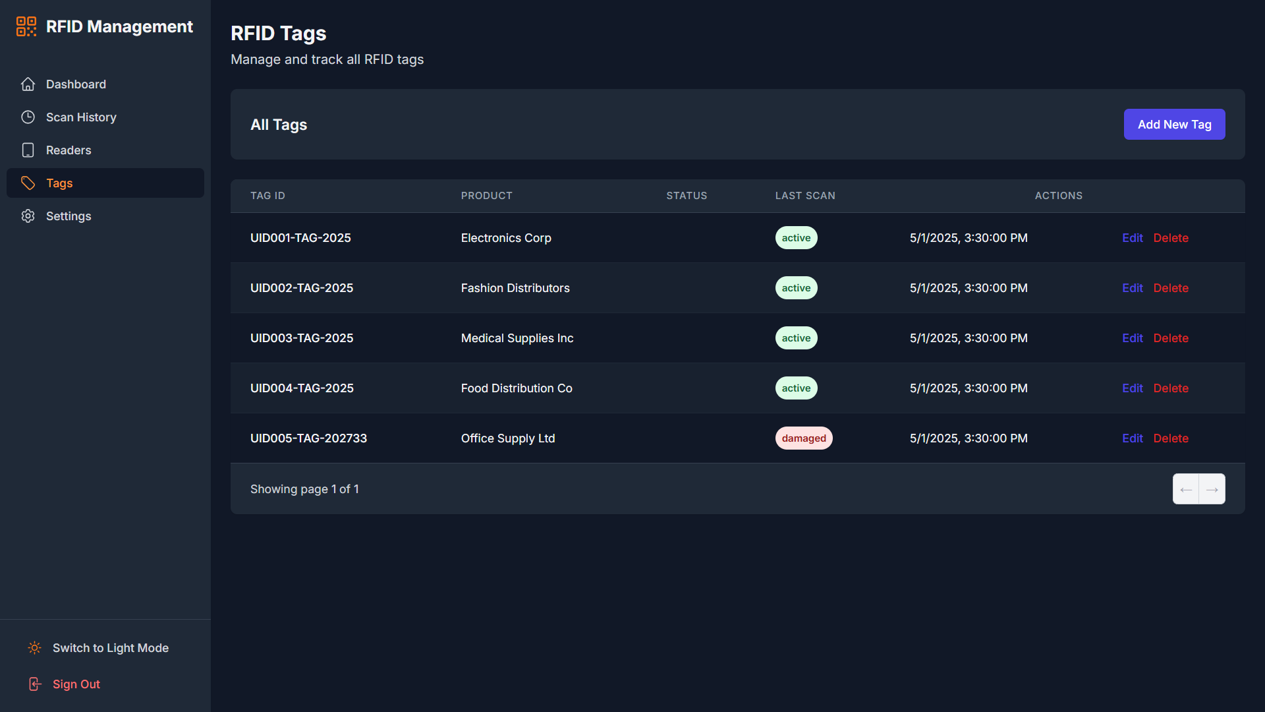
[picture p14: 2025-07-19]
Images/Webapp (4).png

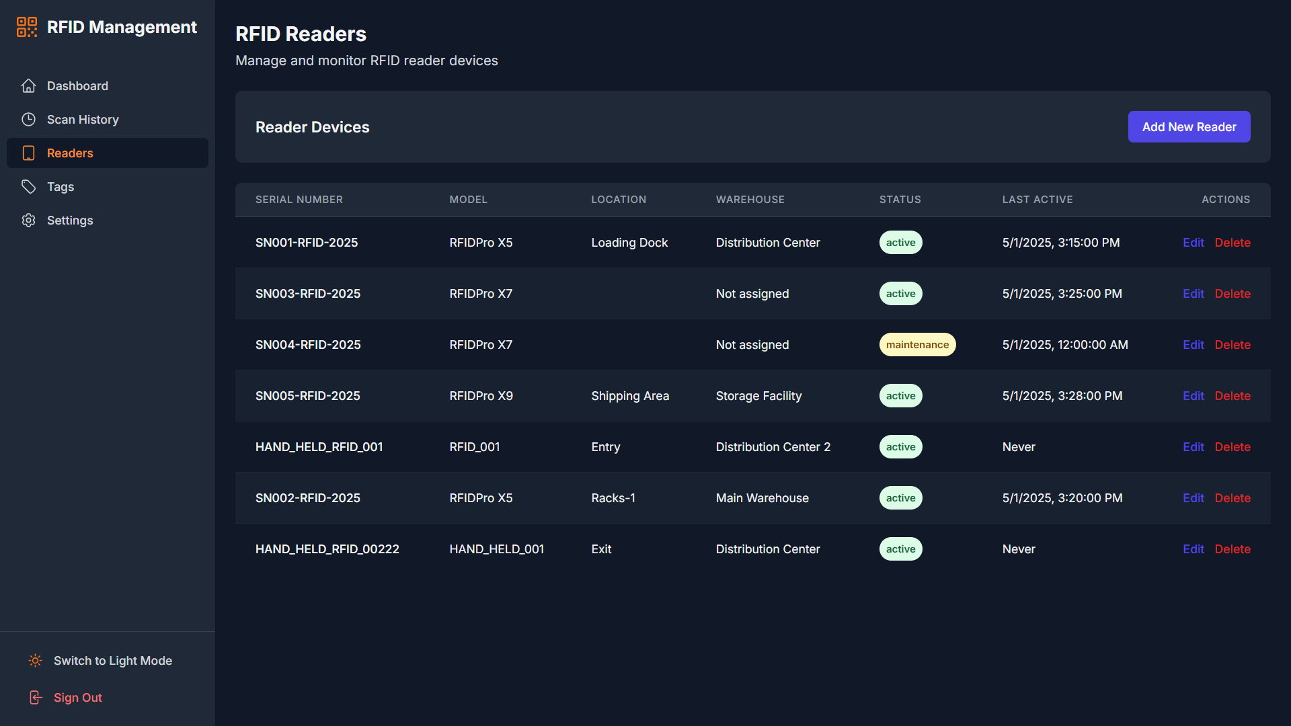
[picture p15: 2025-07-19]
Images/Webapp (3).png

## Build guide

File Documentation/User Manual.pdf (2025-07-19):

# Handheld RFID Reader

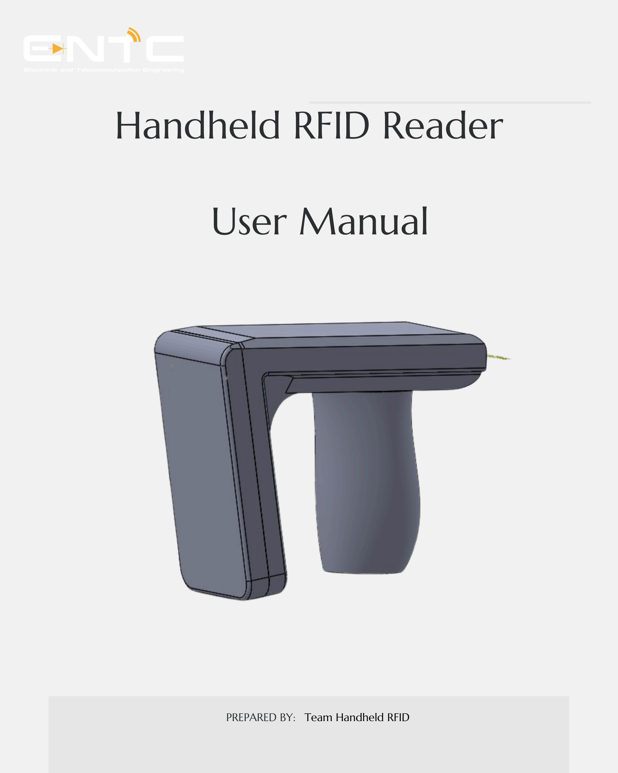
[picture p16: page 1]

# User Manual

PREPARED BY: Team Handheld RFID

# 1.0 IntroductIon

The HF Handheld RFID Reader is a compact, portable device designed for fast and reliable identification and tracking of HF (13.56 MHz) RFID tags. Engineered with ease of use and seamless connectivity in mind, this reader enables users to interact with tagged items through a simple interface while maintaining robust performance across various environments. Whether used for inventory management, access control, healthcare, or retail applications, the HF handheld reader provides a versatile and modern solution for short-range RFID operations. Its ergonomic design, combined with wireless connectivity, makes it ideal for mobile workflows and real-time data collection.

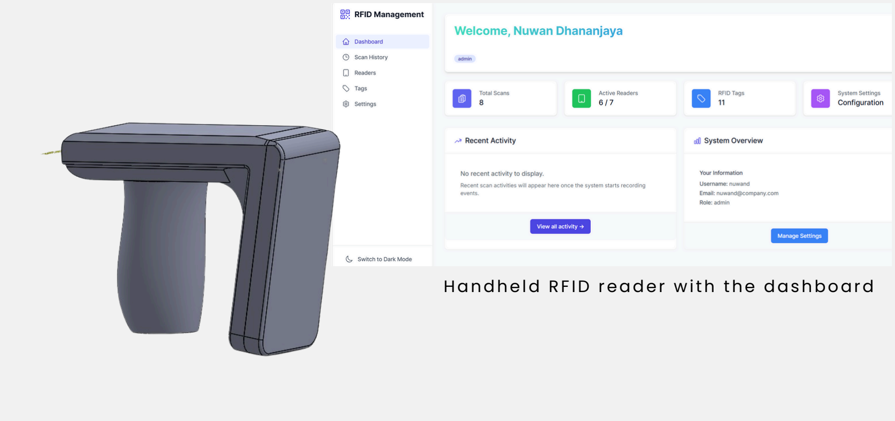
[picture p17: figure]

Handheld RF ID reader with the dashboard

The HF RFID handheld reader can be controlled through a web-based dashboard accessible over Wi-Fi from any device with a modern web browser. Below is an example where it is accessed from a tablet running the Windows operating system:

## RFID.V1 RFID Sled Handheld Reader

Note:
- If you use the web based Dashboard no software installation is required—access the reader entirely through a web interface.
- Ensure the device and the handheld reader are connected to the same Wi-Fi network during setup or operation.
- The dashboard supports all major modern browsers.
Host Platform | Interface Physical Media | Method
Apple iPhone | Web browser (Safari/Chrome) | AppStore App/WebApp
Apple iPad | Web browser (Safari/Chrome) | Appstore App/WebApp
Android Phone | Web browser (Chrome) Wi-Fi | App/WebApp
Windows 10/11 Laptop | Web browser (Edge/Chrome) | Web Dashboard
macOS Laptop/Desktop | Web browser (Safari/Chrome) Wi-Fi | Web Dashboard

## Supported Host Platforms and Connection Types

## 2.1 Product Packaging

1.RFID.V1 : Handheld HF RFID Reader Unit
2.Power Cradle RFID stand
3. Lithium-Ion rechargeable Battery backs,3700Mah (2 pcs)
4. 12V power pack
5.Quick Start Guide (Video Series)
6.User Manual

## 2.2 Key Components

RFID Reader Chip: PN5180
Microcontroller: ATmega32U4
Wi-Fi Module: ESP8266
Power Supply: 2 3.3V Li-Ion rechargeable batteries with a separate charging system cradle. Indicators: LEDs for status and an optional vibration motor for haptic feedback.

# 2.0 Product Specifications

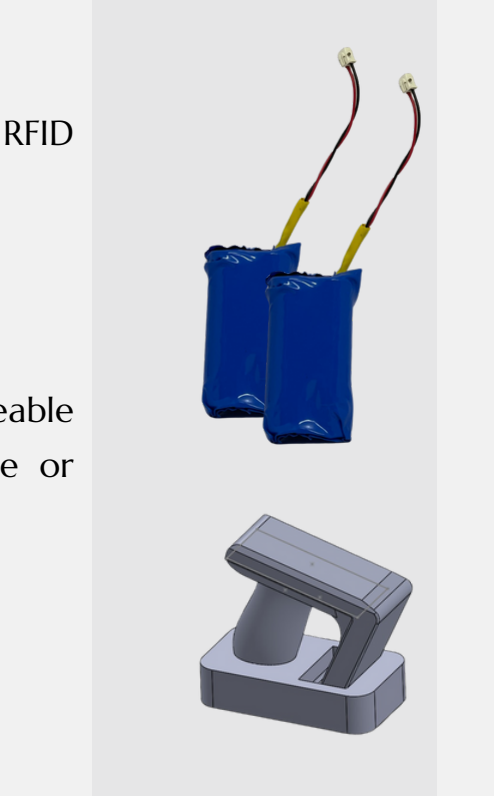
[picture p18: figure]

The following accessories are available for the RFID.V1 Handheld HF RFID Reader

1. RFID.V1 Spare Battery Pack

Each RFID.V1 unit includes two 3700 mAh lithium-ion rechargeable battery packs. Additional batteries are available for extended use or replacement.

2. RFID.V1 Dual Battery Charging Cradle (Power Cradle)

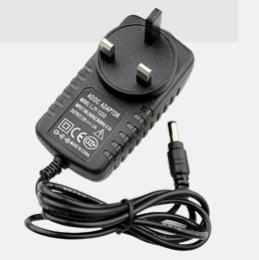
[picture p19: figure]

The Power Cradle serves as both a stand and a dual-slot external battery charger, allowing you to recharge spare battery packs independently of the reader.

3. RFID.V1 12V Power Adapter

A 12V wall adapter compatible with the Power Cradle for efficient charging.

## 3.4 Product Accessories

# 3.0 Getting Started

## 3.1 Introduction

This chapter explains how to set up the device for the first time.

## 3.2 Unpacking

Carefully open the RFID.V1 package and remove all protective plastic coverings. We recommend retaining the original shipping container and internal packaging materials for future storage or transportation.
Verify that the following items are included in the box:

1.RFID.V1 Handheld HF RFID Reader Unit
2.Two (2) Lithium-Ion Rechargeable Battery Packs, 3700 mAh each 3.Power Cradle RFID Stand (Seperate Box)
4.12V Power Pack (for use with the Power Cradle)
5.Quick Start Guide (Video Series Access)
6.User Manual

## 3.3 Features

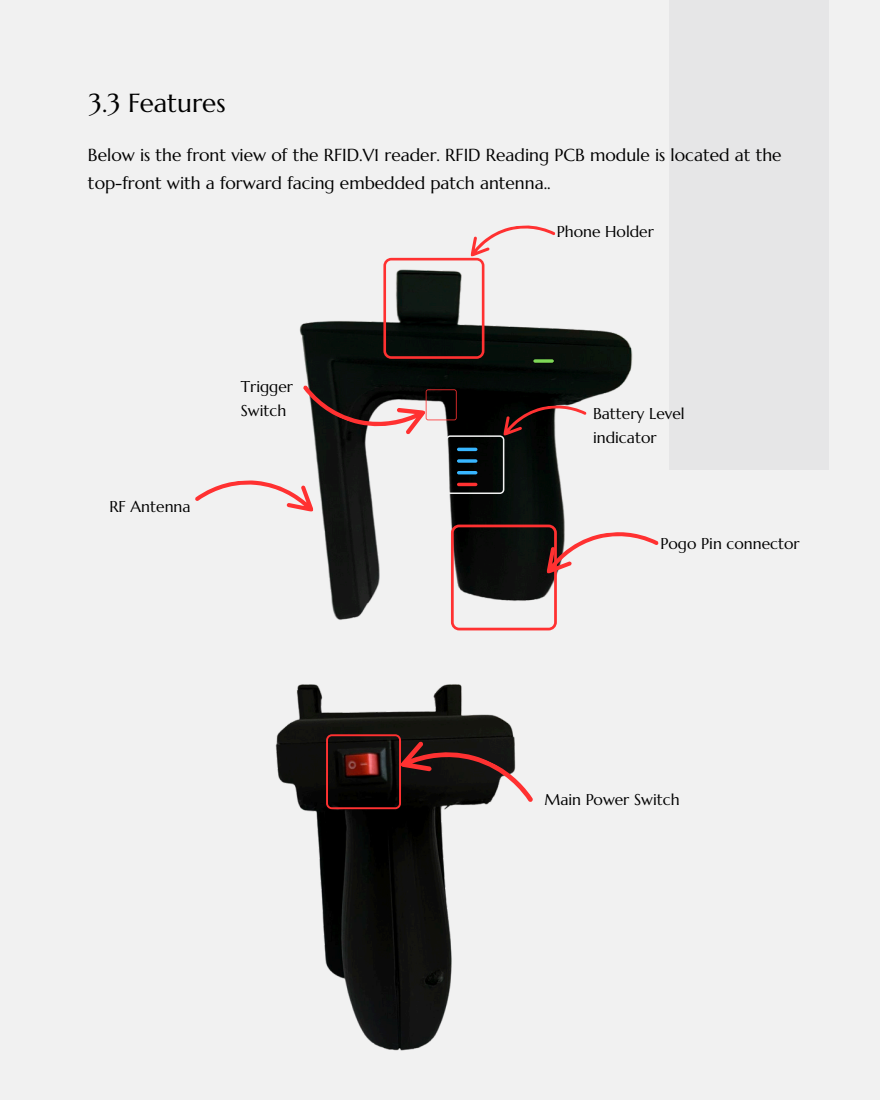
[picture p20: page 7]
Battery Level indicator; Phone Holder; RF Antenna; Trigger Switch

Below is the front view of the RFID.V1 reader. RFID Reading PCB module is located at the
top-front with a forward facing embedded patch antenna..

Pogo Pin connector

Main Power Switch

## 3.4 Powering Up for the first time

## 3.5 Charging the RFID reader

1.Ensure that a fully charged battery is properly inserted into the RFID.V1 unit or that the device is docked in the powered cradle with the 12V adapter connected.
2.Turn on the power switch at the back side of the reader
3. Power LED will turn on to indicate the device is powered. Simultaneously, the red Wi-Fi Setup LED will begin blinking slowly.

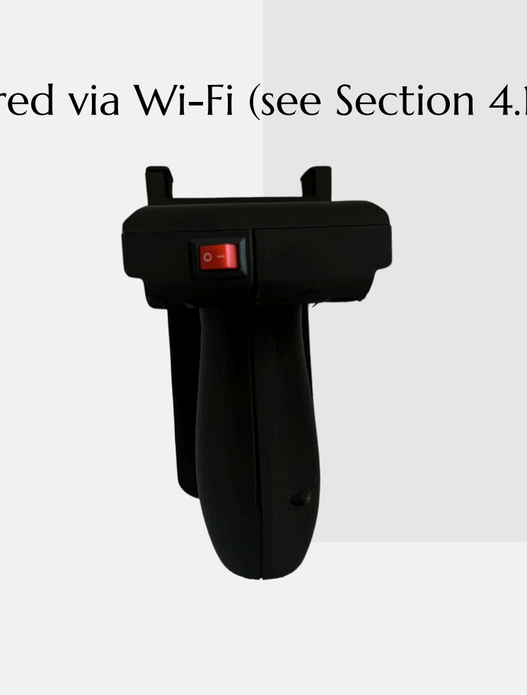
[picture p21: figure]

4.The RFID.V1 is now powered on and ready to be configured via Wi-Fi (see Section 4.1 for connection instructions)

To charge the RFID.V1 handheld reader:

1.Connect the included 12V power adapter to the Power Cradle.
2.Plug the adapter into a standard AC power outlet.
3.Place the RFID.V1 reader securely onto the cradle.
4.Ensure the Battery Charging LED on the side of the reader begins to blink. This indicates that charging is in progress.
5.The current battery level is displayed using a 3-LED battery status array:
- 1 LED = Low charge
- 2 LEDs = Medium charge
- 3 LEDs = Full charge
6. When all three LEDs are lit solid, the battery is fully charged and the Charging LED will turn off or remain solid (depending on device firmware).

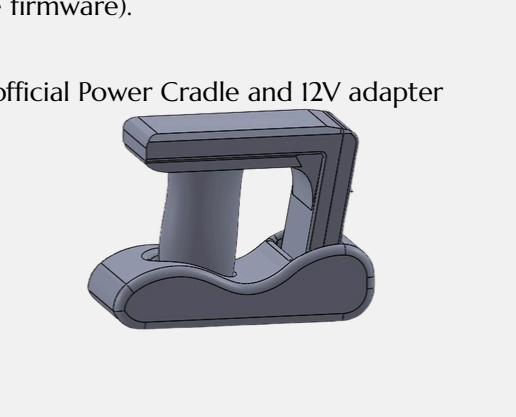
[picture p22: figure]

Note: For optimal battery health, always use the official Power Cradle and 12V adapter supplied with the RFID.V1.

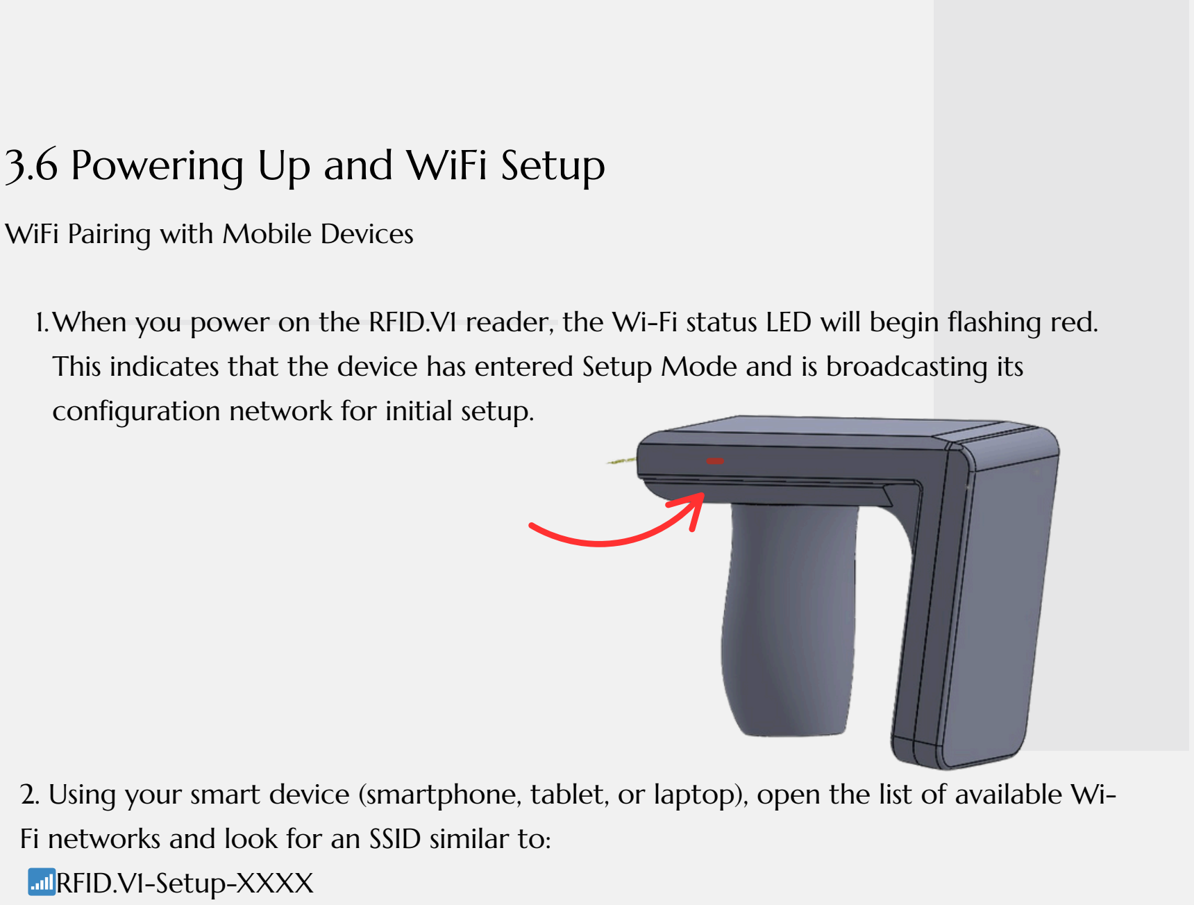
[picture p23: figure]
3.6 Powering Up and WiFi Setup; WiFi Pairing with Mobile Devices; configuration network for initial setup.; 📶RFID.V1-Setup-XXXX

1.When you power on the RFID.V1 reader, the Wi-Fi status LED will begin flashing red. This indicates that the device has entered Setup Mode and is broadcasting its

2. Using your smart device (smartphone, tablet, or laptop), open the list of available Wi-Fi networks and look for an SSID similar to:

(where XXXX is a unique identifier for your device)
3. Connect to the RFID.V1-Setup network.
Password: 1234
4. Once connected, open a web browser on your device and enter the following address into the URL bar:
http://192.168.4.1
5. You will be directed to the RFID.V1 Setup Page. From here, you can:

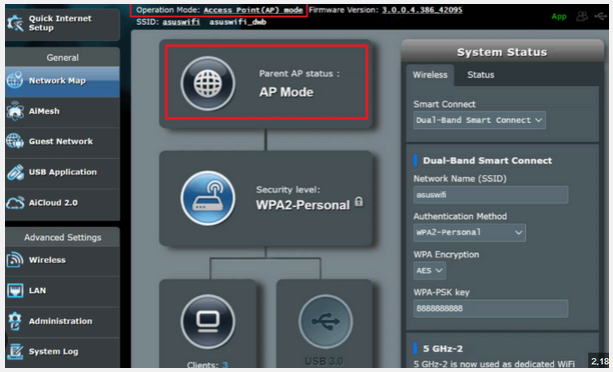
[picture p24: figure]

- View available Wi-Fi networks
- Select your local Wi-Fi network
- Enter your Wi-Fi password
- Save and reboot the device

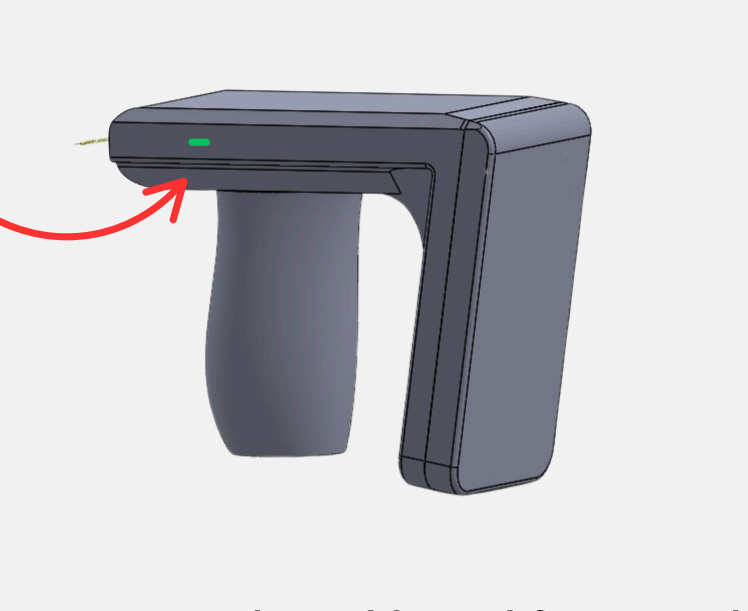
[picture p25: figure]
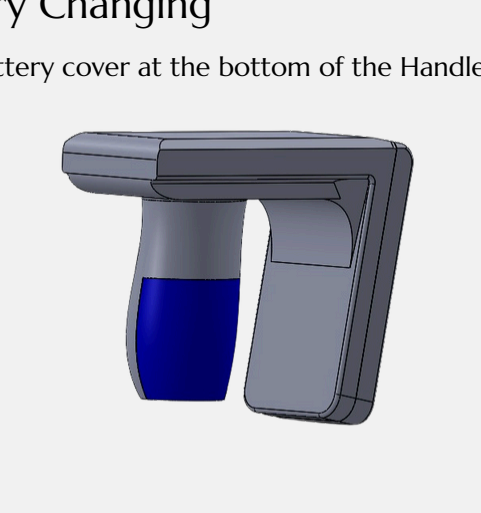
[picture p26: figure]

1. Slide the battery cover at the bottom of the Handle
2. Remove the JST connector of the battery. from the Circuit board
3. Get the Battery Outside and Connect the new battery unit
4. Close the Lid safely
6. After rebooting, the RFID.V1 will automatically connect to the selected Wi-Fi network. The LED will turn solid green to indicate a successful connection.
7. You can now access the RFID.V1 Web Dashboard from any browser on the same network by entering its local IP address (shown during setup or available via the connected router's device list).

## 4.7 Battery Changing

## 3.9 Web App

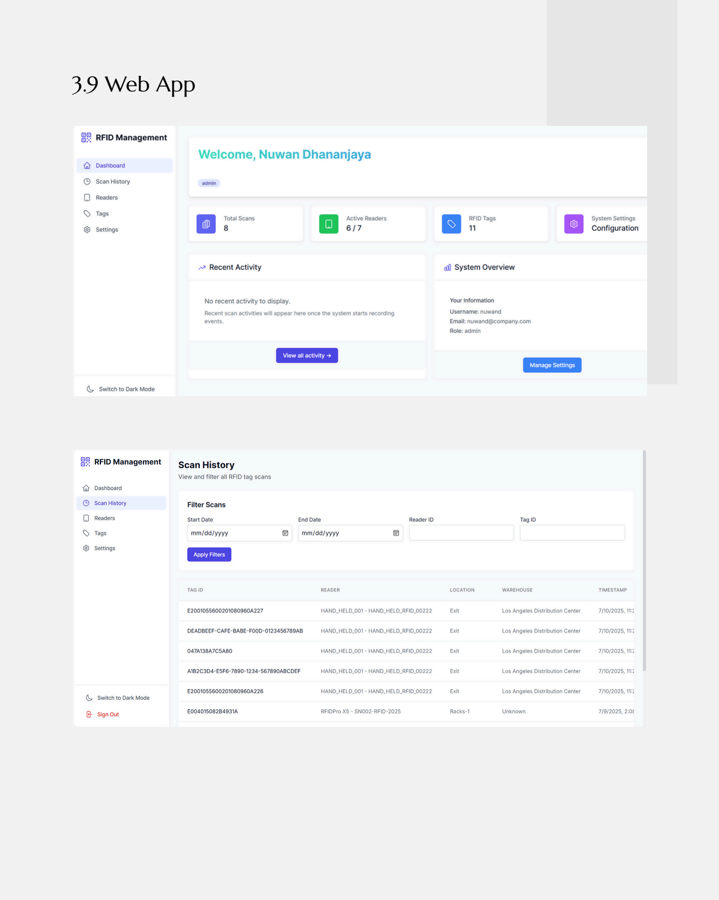
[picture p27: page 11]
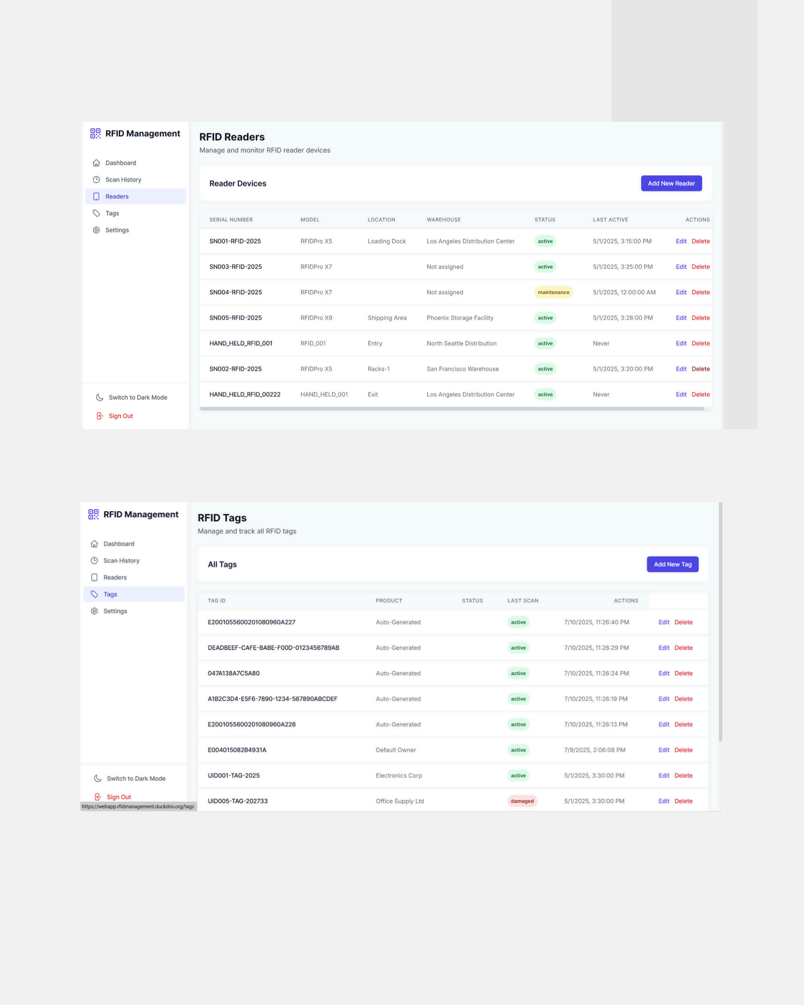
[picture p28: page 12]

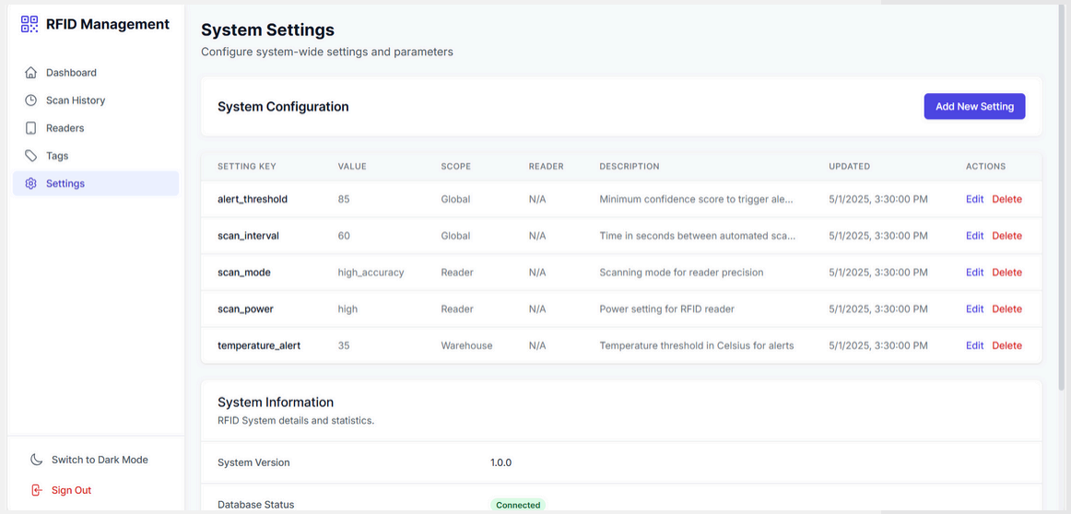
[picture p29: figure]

## 3.10 Mobile Application

Step 1 : After installing the app, open the RFID Manager app and log in with your credentials to view the dashboard

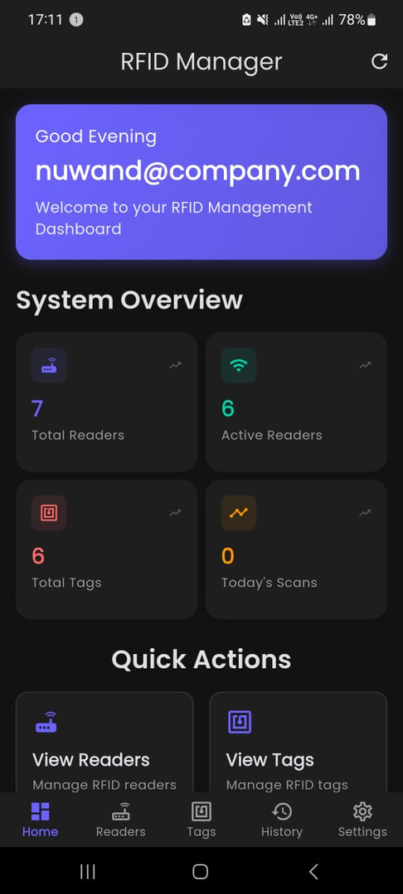
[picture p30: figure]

Step 2 : Tap the "Settings" icon to access your profile and adjust app settings

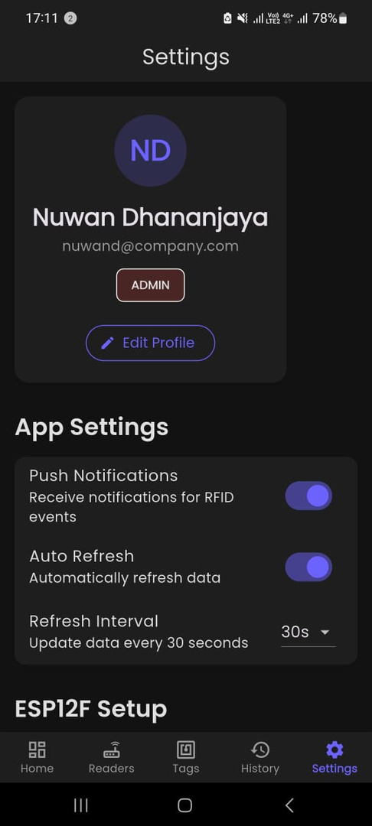
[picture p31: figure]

Step 3 : In the "ESP12F Setup" section, tap "Configure ESP12F WiFi" and select "Open web portal at 192.168.4.1" to set up the WiFi connection.

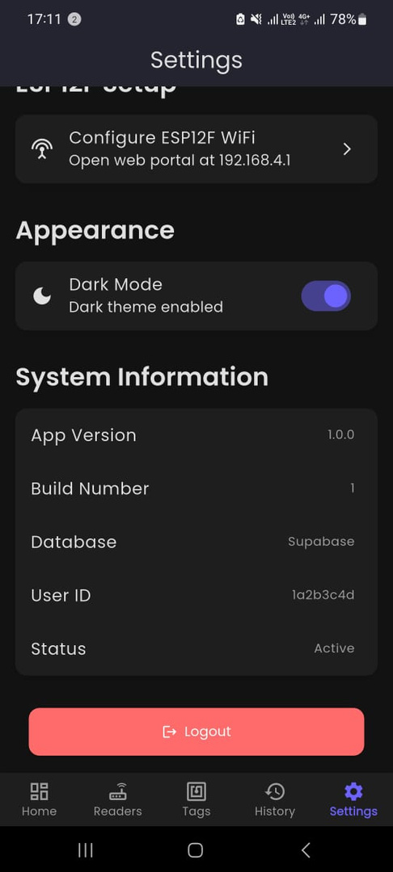
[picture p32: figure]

Step 4 : Afrer cilcking the scan button the user will be able to scan tags

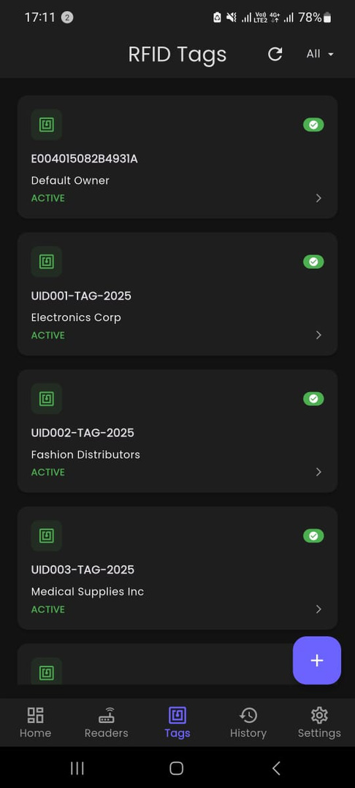
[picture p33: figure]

Step 5 : Tap History to review recent scans

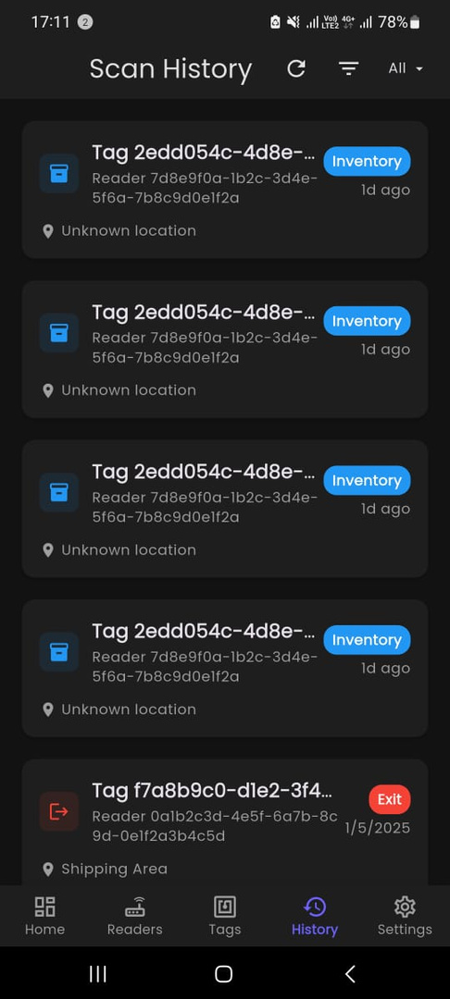
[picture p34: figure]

Step 6 : User will get a notification saying the scannig was done successfully.

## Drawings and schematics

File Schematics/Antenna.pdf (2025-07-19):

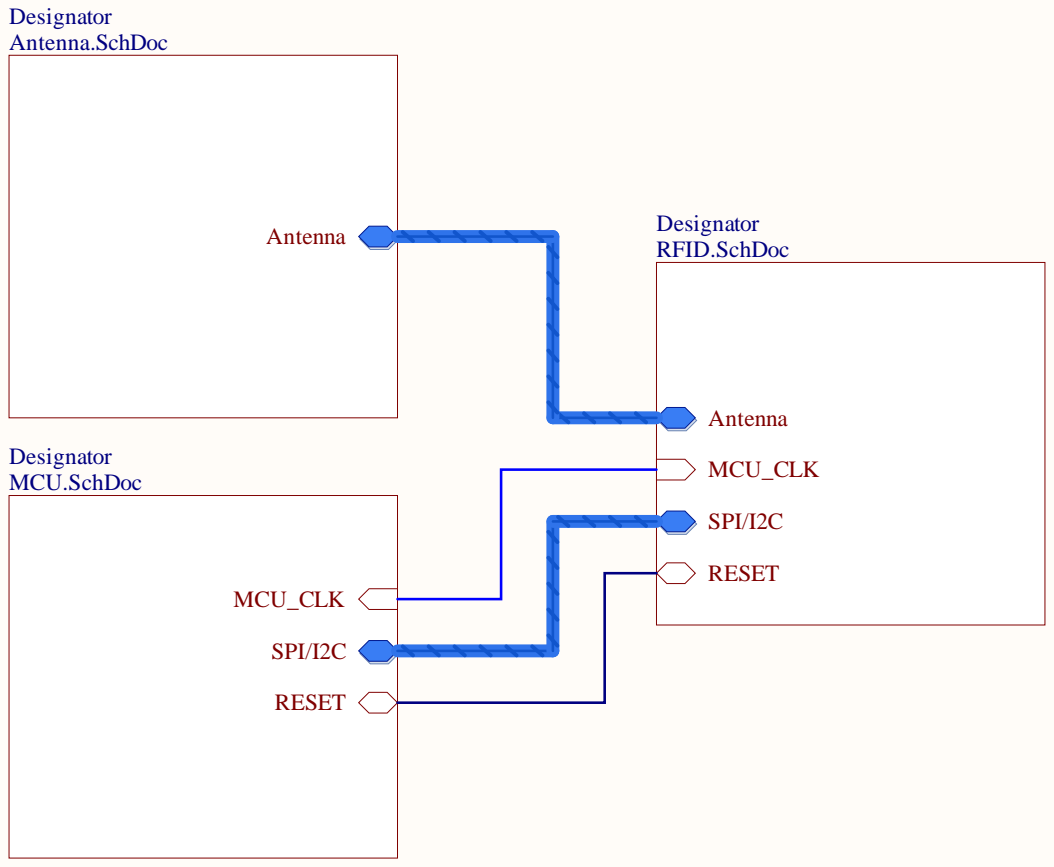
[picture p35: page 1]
Date:; Sheet of; File:; Overview.SchDoc; Drawn By:; HAPUARACHCHI HADND

Title
HandHeld RFID Reader- Antenna

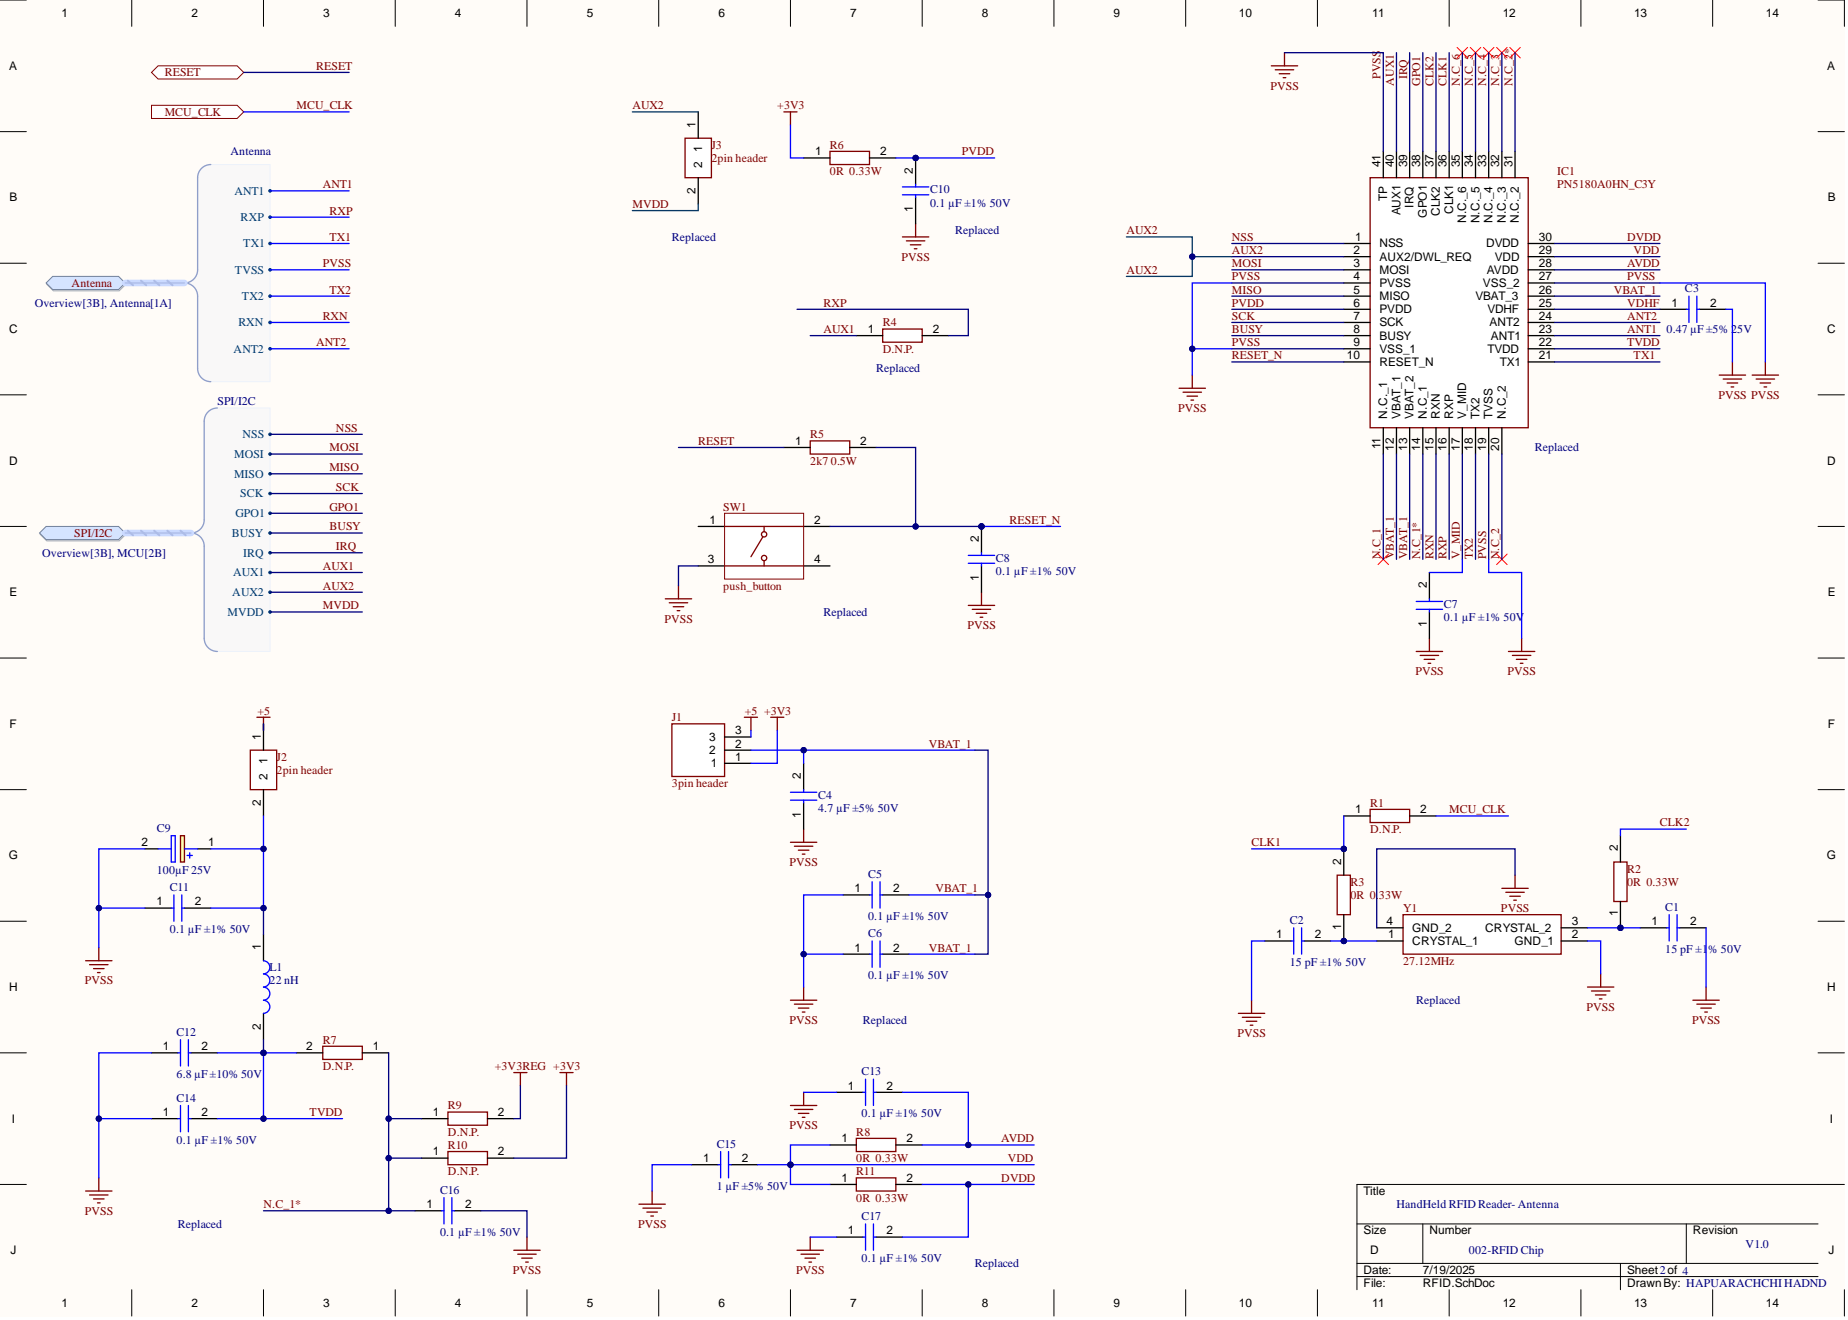
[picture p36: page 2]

Title
HandHeld RFID Reader- Antenna

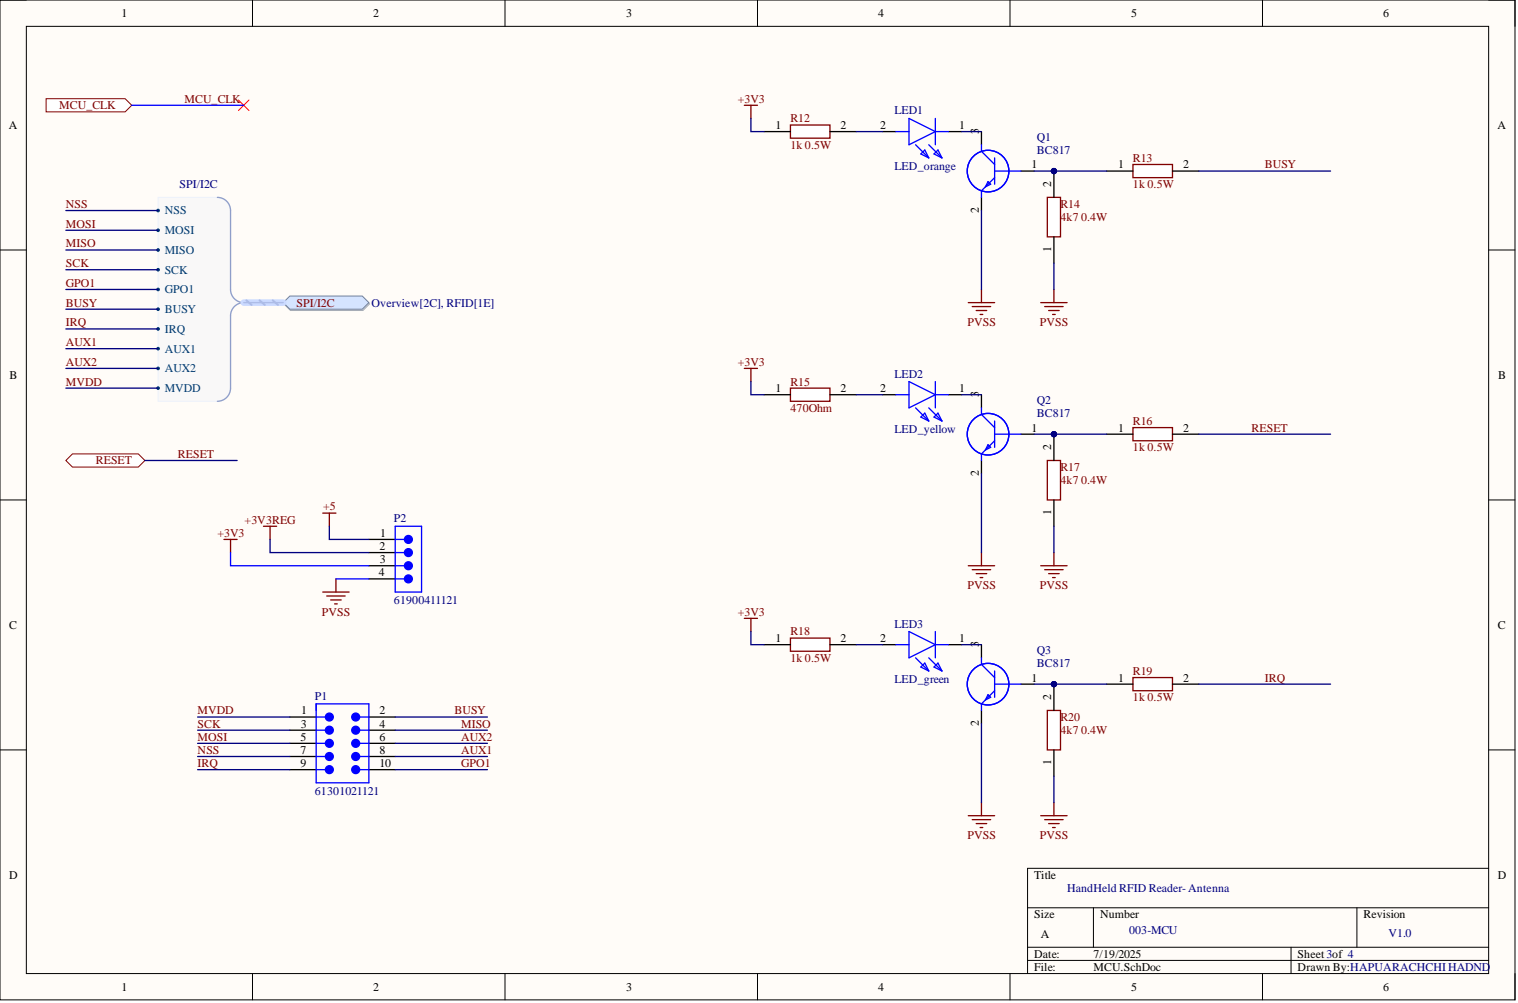
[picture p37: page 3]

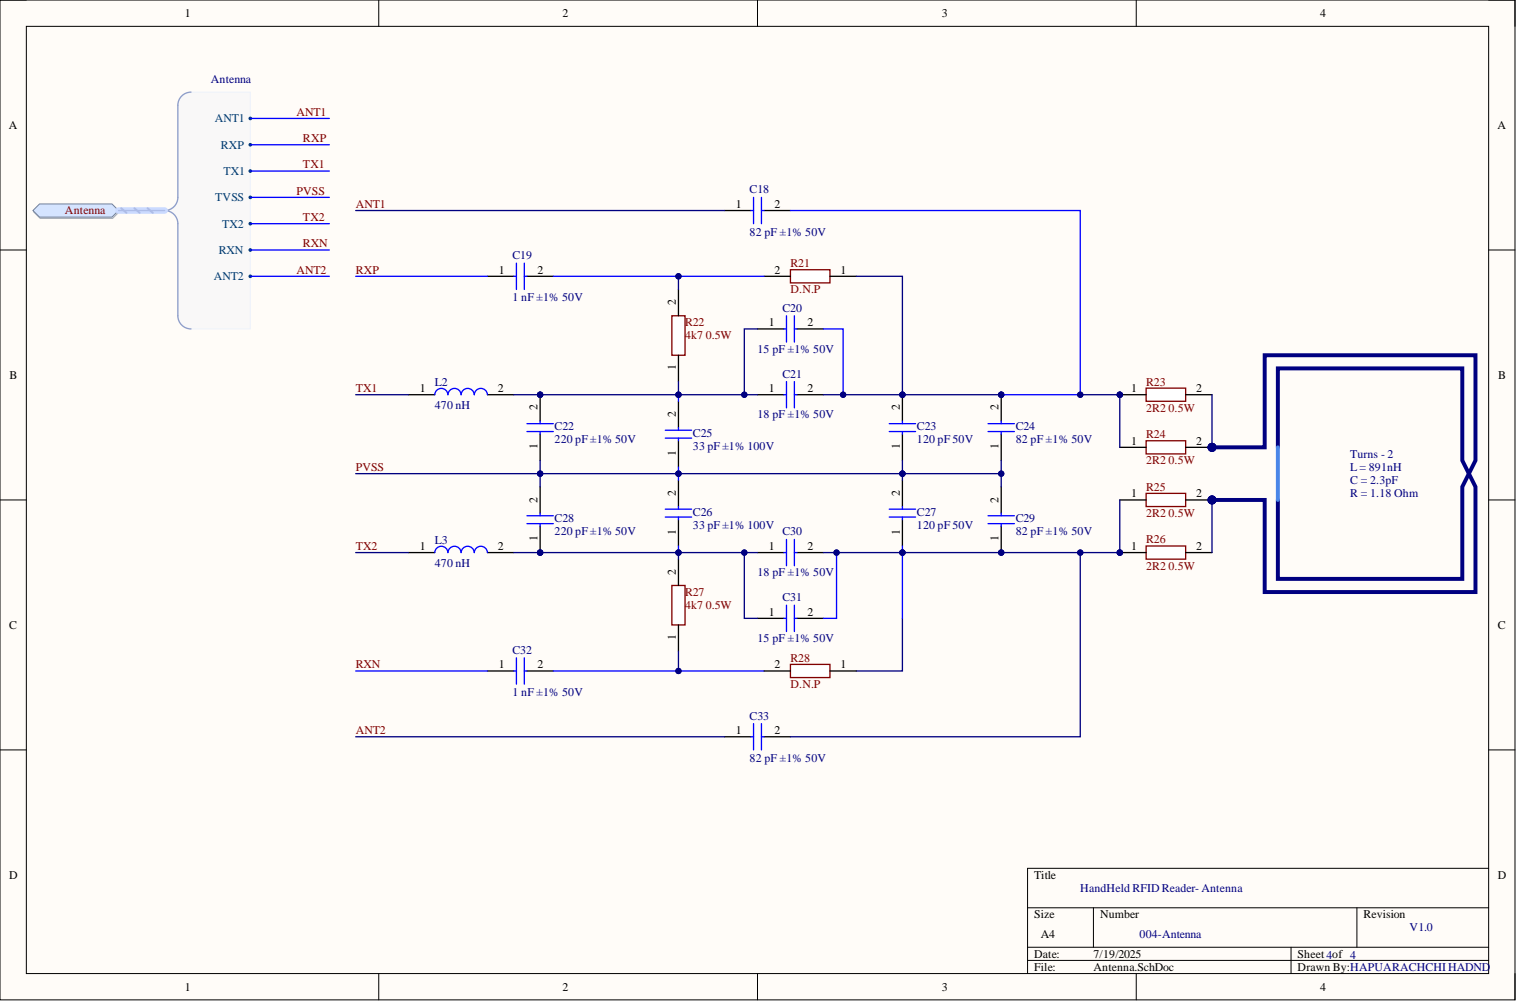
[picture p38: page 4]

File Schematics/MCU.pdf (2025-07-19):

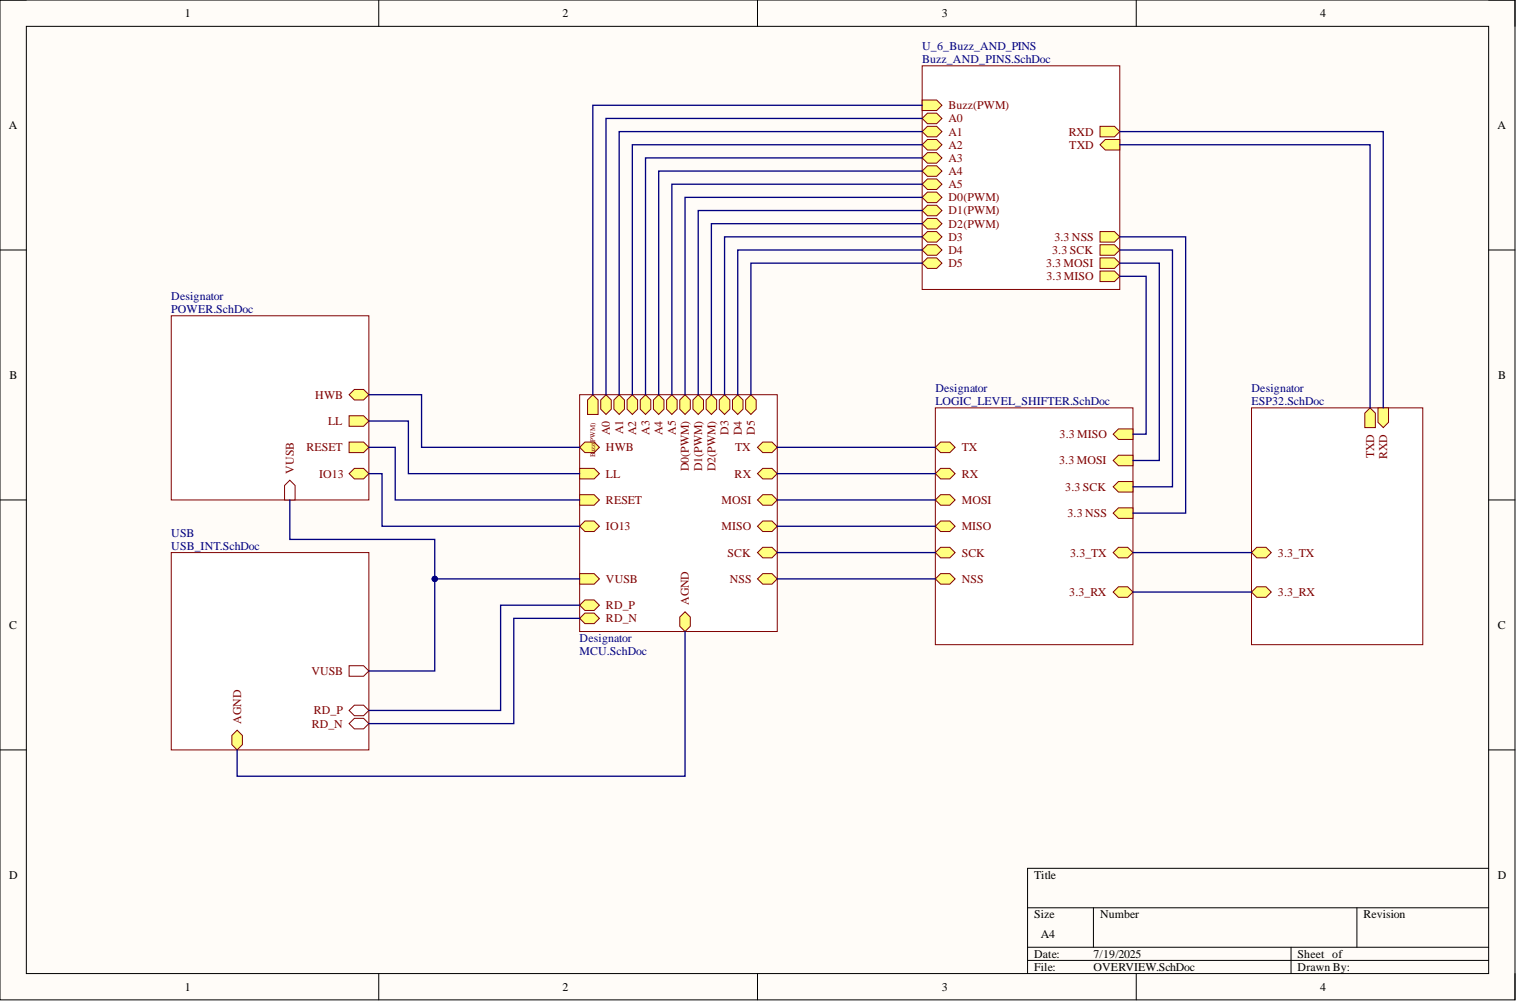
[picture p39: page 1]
Date:; Sheet of; File:; OVERVIEW.SchDoc; Drawn By:; 3.3 MISO; 3.3 MOSI; 3.3 SCK; 3.3 NSS; 3.3 NSS 3.3 SCK 3.3 MOSI 3.3 MISO

HWB TX LL RX RESET MOSI IO13 MISO SCK VUSB NSS RD_P RD_N

VUSB RD_P A RD_N

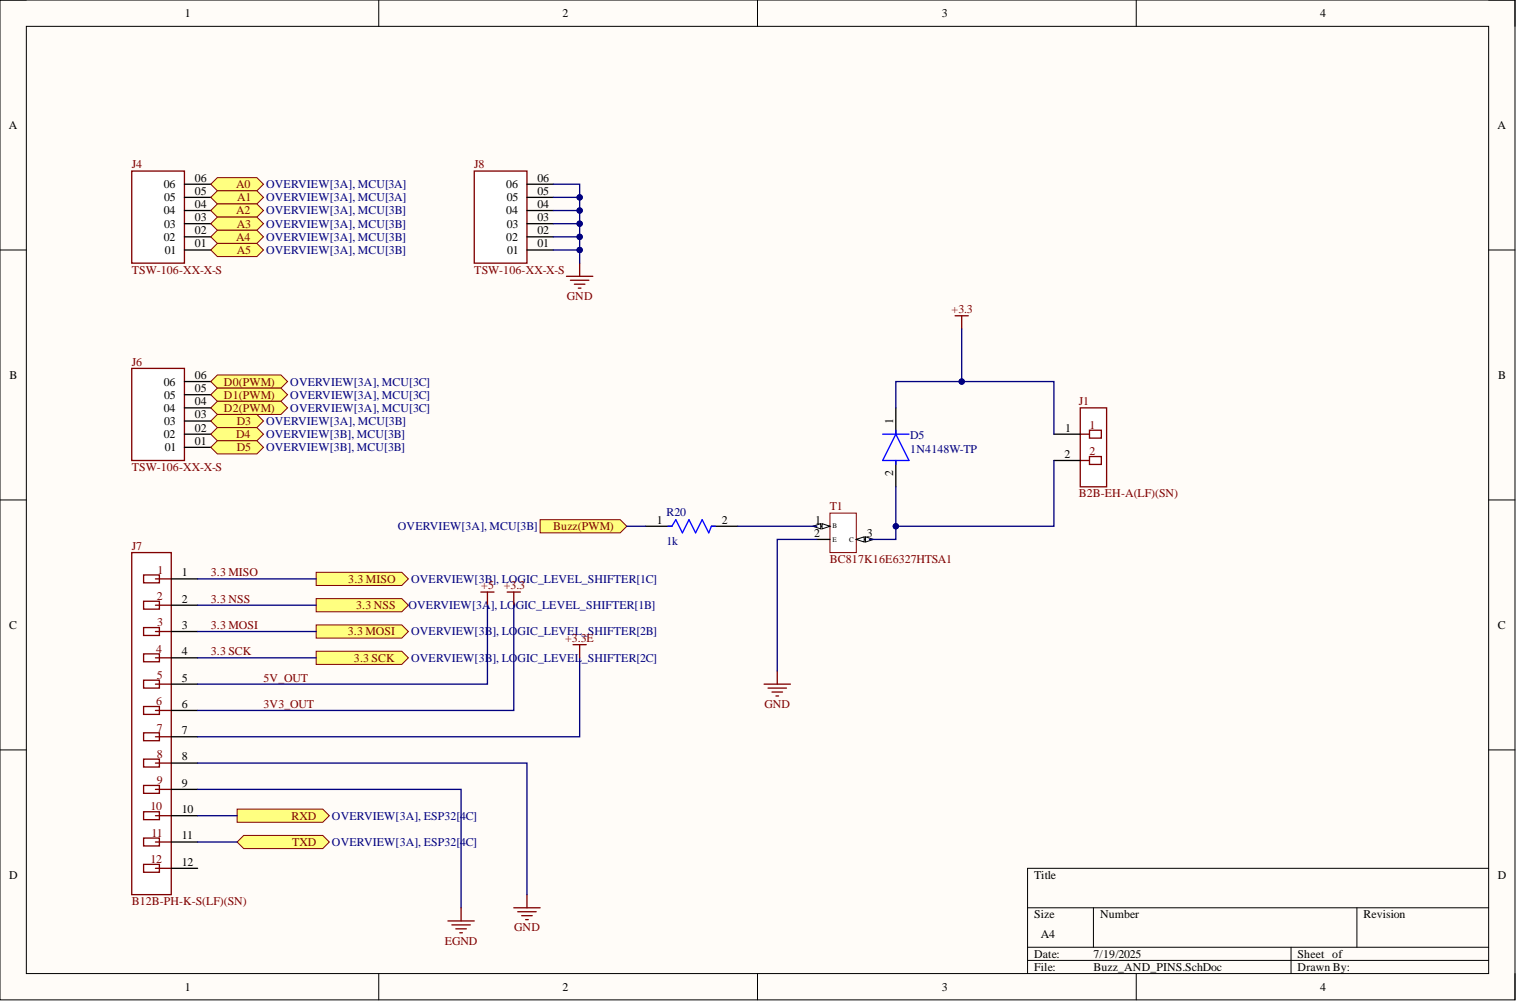
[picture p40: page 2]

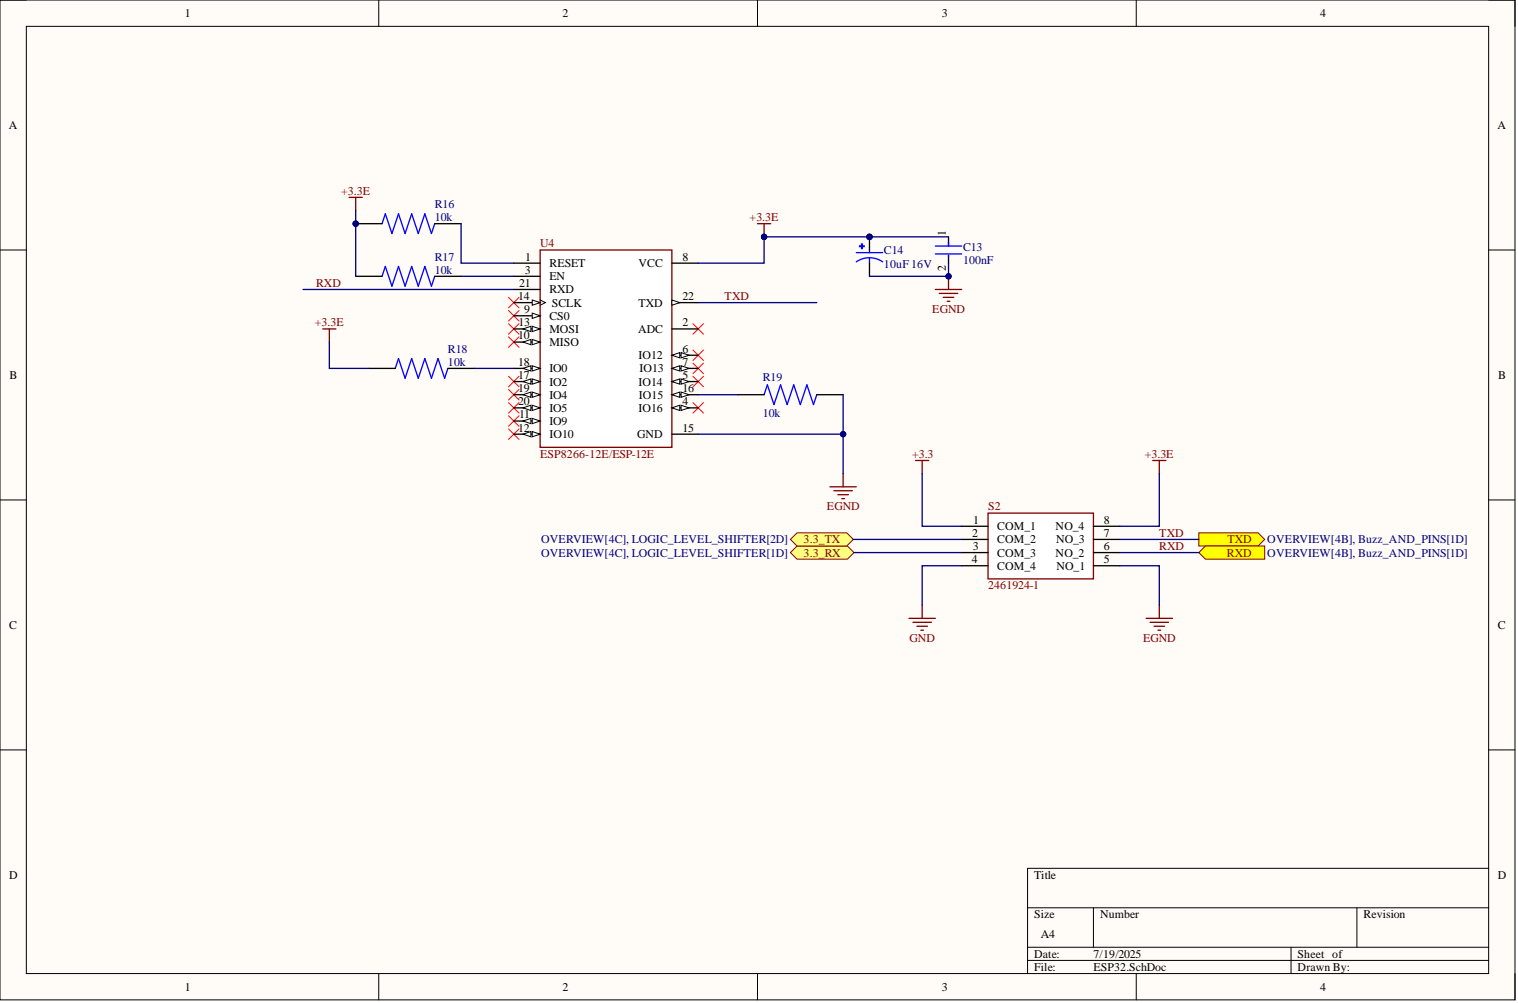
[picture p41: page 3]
File:; ESP32.SchDoc; Drawn By:; RESET 1 EN 3 RXD 21 SCLK 14 CS0 9 MOSI 13 MISO 10; TXD; OVERVIEW[4B], Buzz_AND_PINS[1D]; RXD; COM_1 1 COM_2 2 COM_3 3; COM_4 4; OVERVIEW[4C], LOGIC_LEVEL_SHIFTER[1D]; OVERVIEW[4C], LOGIC_LEVEL_SHIFTER[2D]

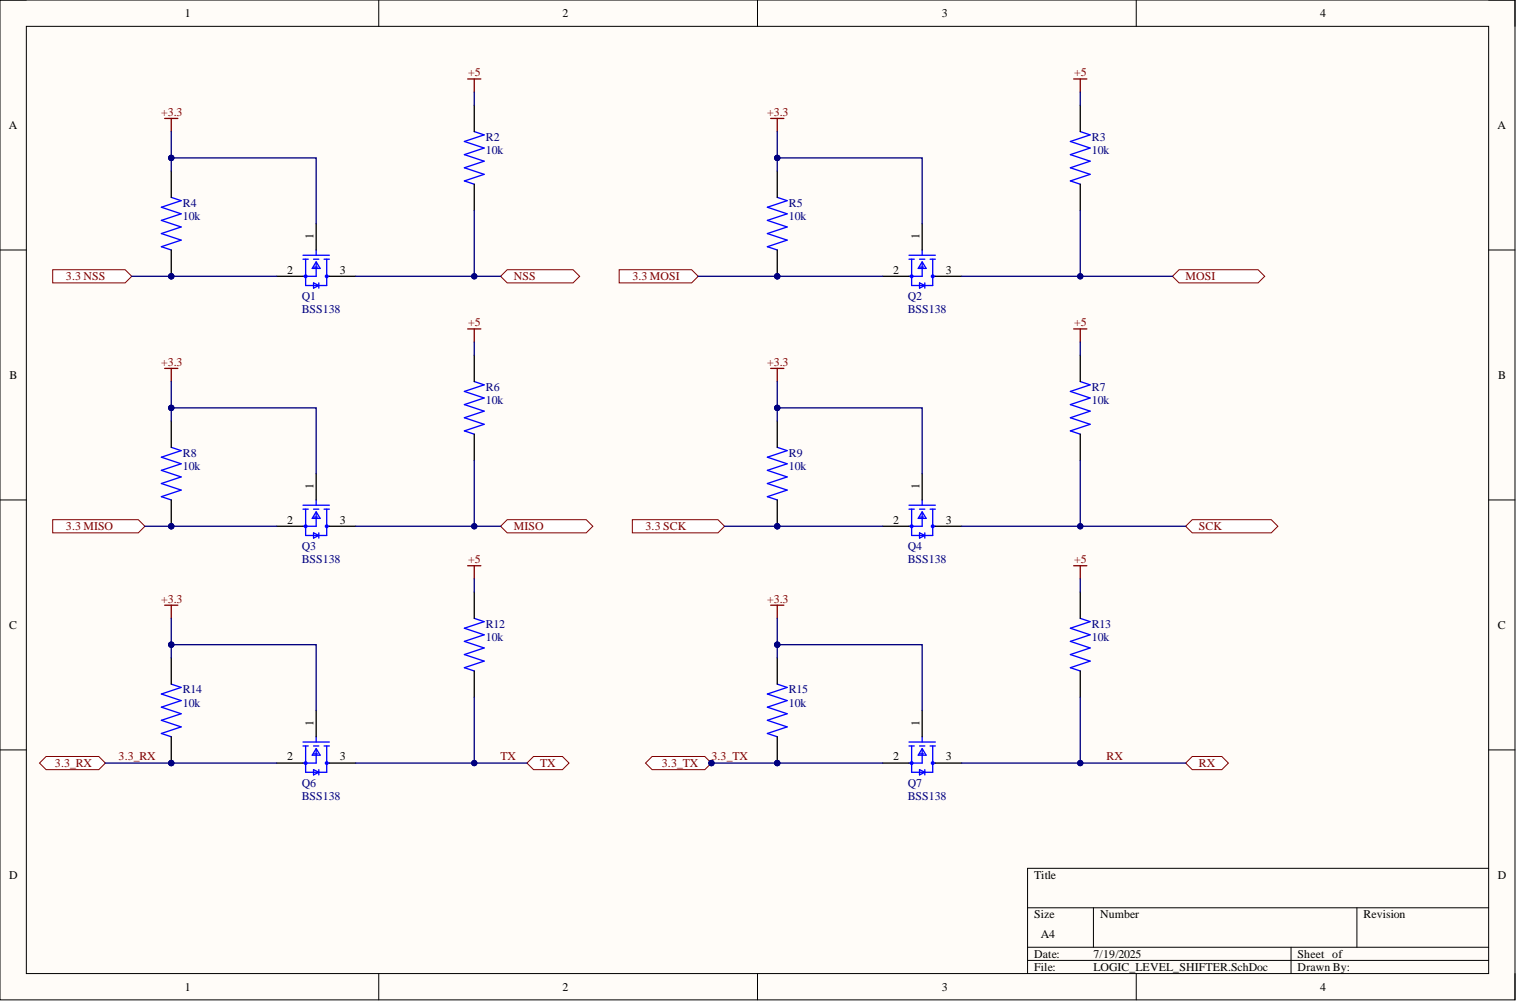
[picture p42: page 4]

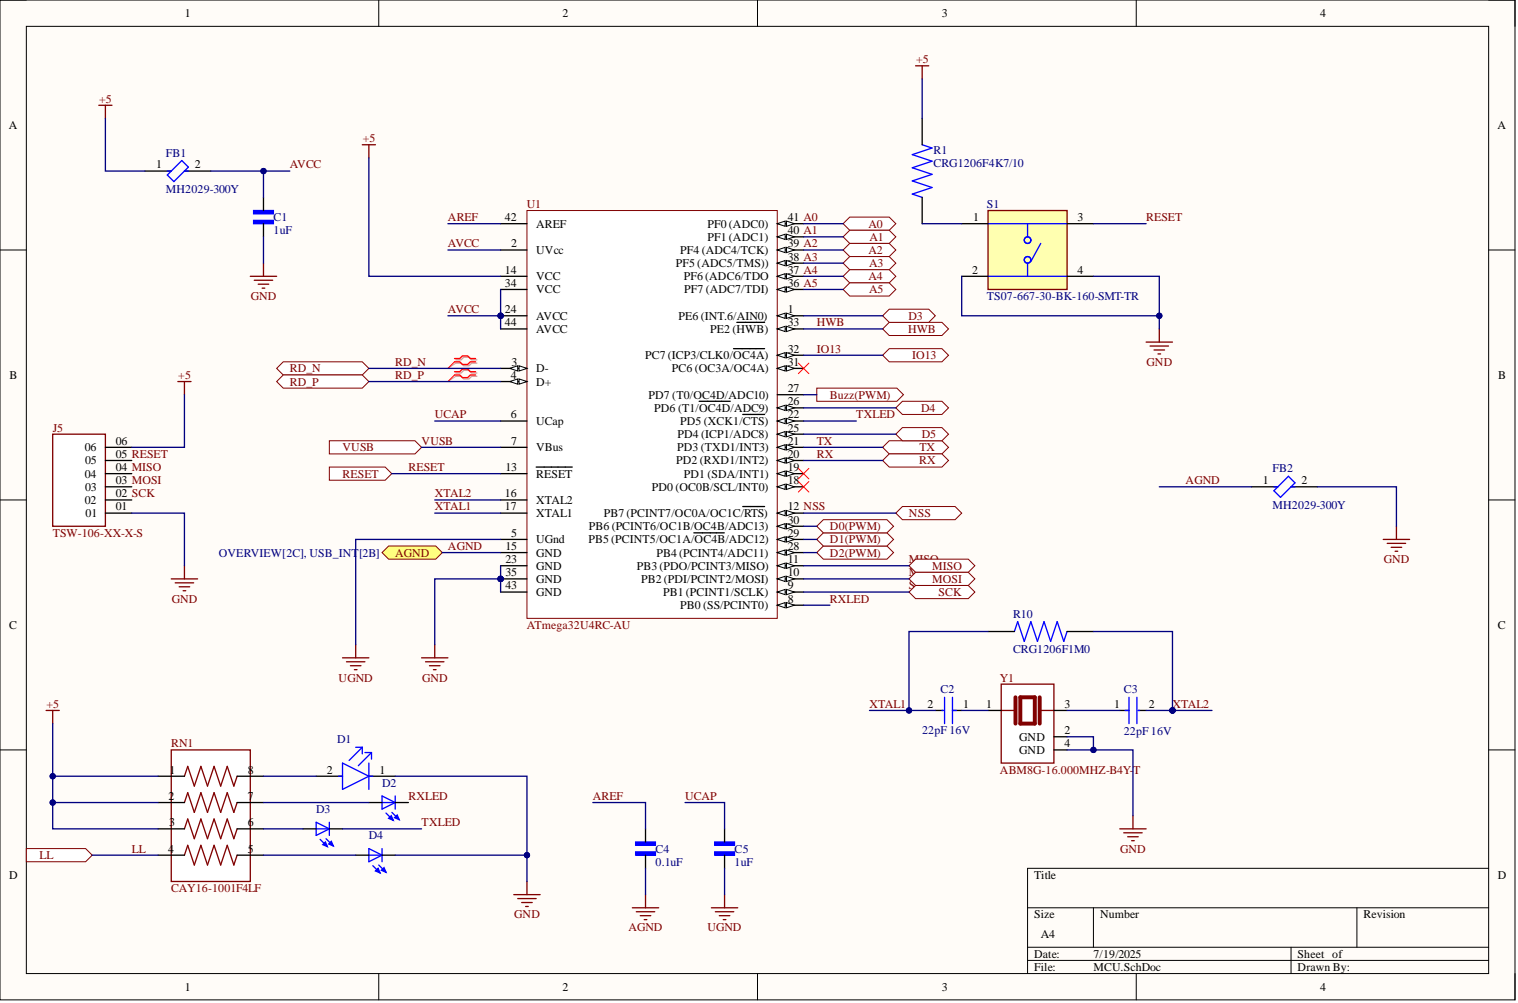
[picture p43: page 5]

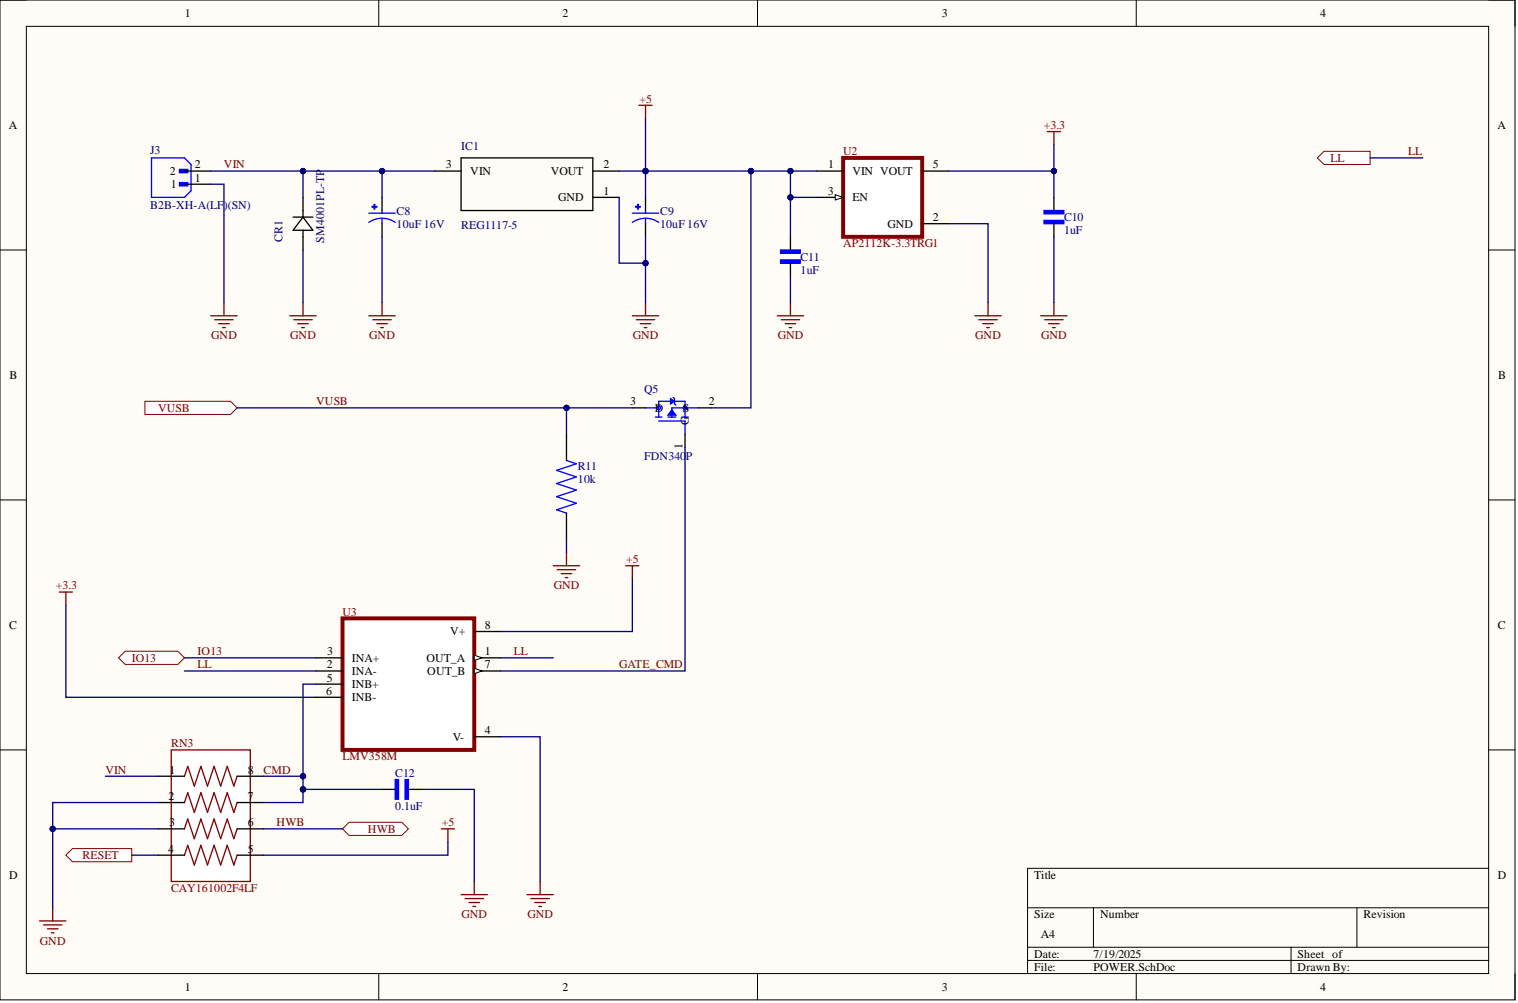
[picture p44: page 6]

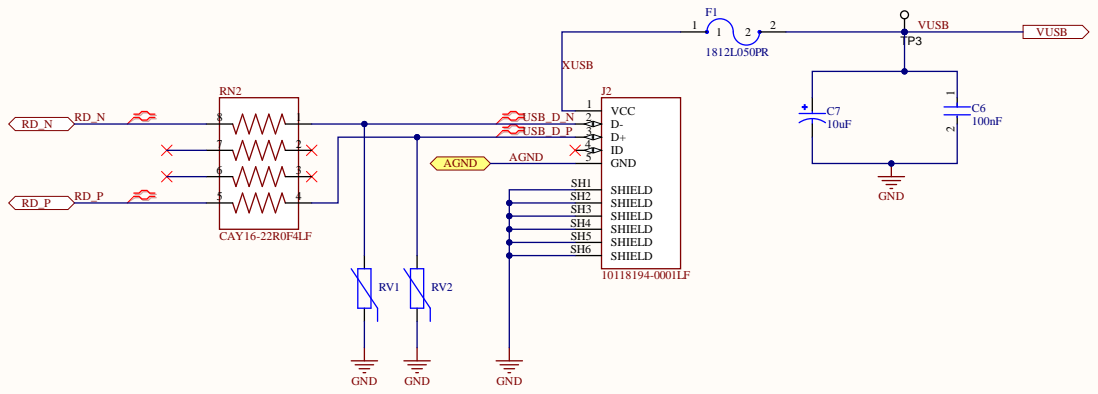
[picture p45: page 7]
GND

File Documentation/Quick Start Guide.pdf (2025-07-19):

## Need More Help?

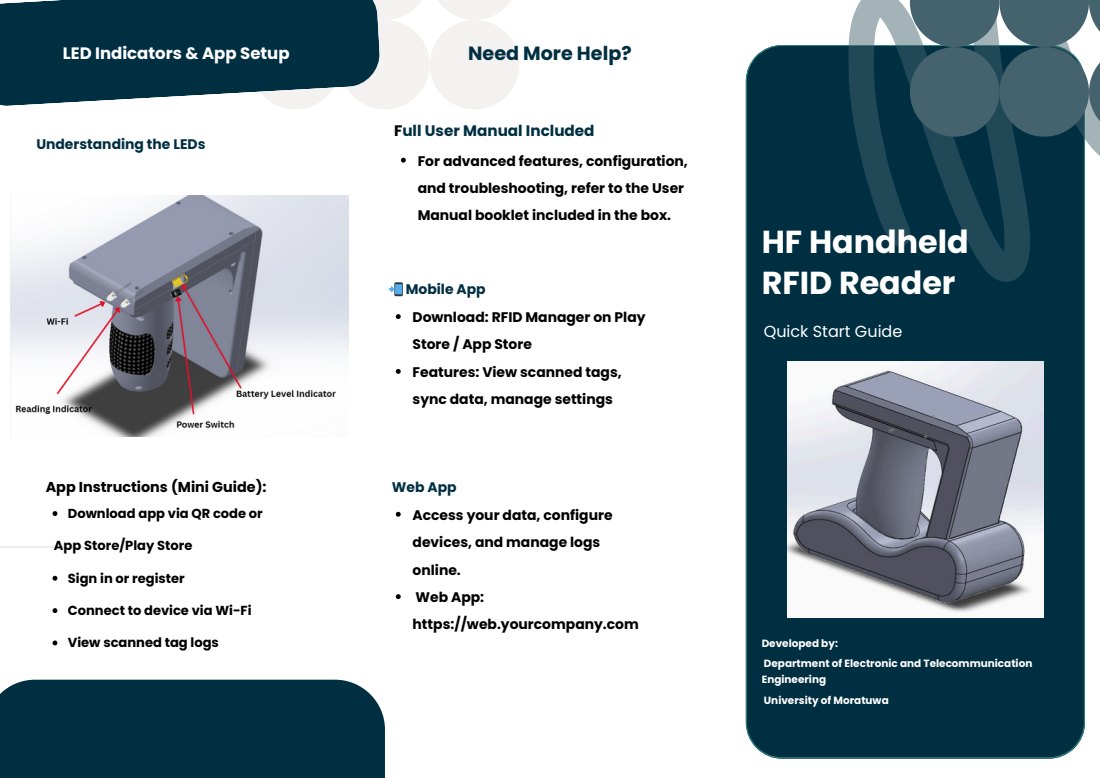
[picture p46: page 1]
HF Handheld RFID Reader

LED Indicators & App Setup

Full User Manual Included
For advanced features, configuration,
and troubleshooting, refer to the User
Manual booklet included in the box.

Understanding the LEDs

📲 Mobile App
Download: RFID Manager on Play
Store / App Store
Features: View scanned tags,
sync data, manage settings

Quick Start Guide

App Instructions (Mini Guide):
Download app via QR code or
App Store/Play Store
Sign in or register
Connect to device via Wi-Fi
View scanned tag logs

Web App
Access your data, configure
devices, and manage logs
online.
Web App:
https://web.yourcompany.com

Developed by:
Department of Electronic and Telecommunication
Engineering
University of Moratuwa

## Device overview

What’s in the Box | Setup and Instructions

1/2 LEDS --> Charging,; 4.Scan a tag

1. Charge the Reader

Place in the cradle

1. Handheld RFID Reader
2. Power Cradle
3.Charging Cable
4. Quick Start Guide
5. full manual

All 3 LEDs --> Full

2.Power ON/OFF

Hold the power button for 3
seconds

3.Connect to Wi-Fi

1. Phone Holder
2. Wi-Fi Indicator
3. Reading Indicator
4. Ergonomic Handle with better grip
5. Power Switch
6. Battery level Indicator
7. Antenna

Open mobile app and follow
pairing steps

LED indicates connection
status

Aim at tag and press trigger

5.View Tag Data

Scans sync automatically to
the app/database

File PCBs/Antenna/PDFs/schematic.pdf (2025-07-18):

1

2

Title; Size; Number; Revision; Date:; Sheet of; File:; C:\Users\..\Overview.SchDoc; Drawn By:; Antenna; Designator Antenna.SchDoc; MCU_CLK; SPI/I2C; Designator RFID.SchDoc; Designator MCU.SchDoc


TX1 TP AUX¹ IRQ GPO¹ CLK² CLK¹ N.C_6 N.C_5 N.C_4 N.C_3 N.C_2

1

2

Title; Size; Number; Revision; Date:; Sheet of; File:; C:\Users\..\MCU.SchDoc; Drawn By:; MCU_CLK; Overview[3C], RFID[2B]; NSS MOSI MISO SCK GPO1 BUSY IRQ AUX1 AUX2 MVDD; SPI/I2C; NSS MOSI MISO SCK GPO1; BUSY; Overview[3C], RFID[1E]; IRQ AUX1 AUX2 MVDD; PN5180 RFID Antenna; HAPUARACHCHI HADND

1

2


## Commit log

2025-07-18 Add files via upload
    init
    [Antenna.SchDoc, Antenna_Order.PcbLib, Antenna_Order.SchLib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]
2025-07-19 Moved Antenna, MCU to PCBs directory
    [Antenna.SchDoc, Antenna_Order.PcbLib, Antenna_Order.SchLib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]
2025-07-19 Schematic PDFs
